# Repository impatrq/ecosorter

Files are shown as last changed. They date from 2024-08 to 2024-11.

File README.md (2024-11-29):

<div align="center">

# [Ecosorter - IMPA TRQ](https://www.instagram.com/proyecto_ecosorter24/)

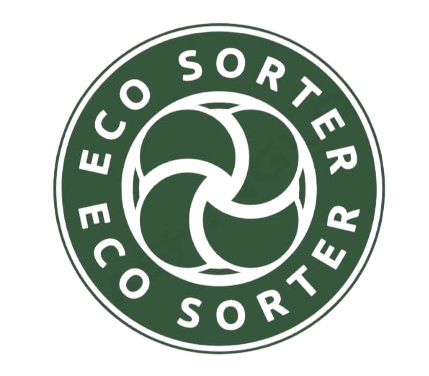
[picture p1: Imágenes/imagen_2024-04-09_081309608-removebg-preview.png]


&nbsp;

| Página web | Email | Instagram |
|---|---|---|
|[Ecosorter Web](https://eco-sorter.github.io/ecosorter/)|ecosorterimpa2024@gmail.com|[@proyecto_ecosorter24](https://www.instagram.com/proyecto_ecosorter24/)|

&nbsp;

</div>

## ¿Qué es Ecosorter?
Eco Sorter es un prototipo de un sistema de reciclaje inteligente el cual tiene como objetivo optimizar el proceso de reciclaje clasificando los residuos que se depositan en él, mediante el uso de sensores.

## ¿Cómo funciona?
El residuo depositado cae en una cesta guiada por un sistema de engranajes. Dentro de la cesta, se encuentran varios tipos de sensores que ayudan a clasificar el residuo, mientras que una cámara monitorea constantemente para determinar si es reciclable o no. Una vez identificado el tipo de residuo, el sistema de engranajes desplaza la cesta hacia la división correspondiente. La base de la cesta se abre, liberando su contenido en el recipiente adecuado. Los residuos se clasificarán en cuatro categorías.

## ¿Quiénes somos?

Somos un grupo de alumnos de E.E.S.T. N°7 "Taller Regional Quilmes" (IMPA).

### Cordoba Facundo
* 📧 facumate32@gmail.com

### Enrique Enzo
* 📧 kotamatsukami890@gmail.com

### Estevez Juan
* 📧 juanchiestevez2006@gmail.com

### Lelio Gaston
* 📧 gastonlelio05@gmail.com

### Seoane Facundo
* 📧 facuseoane40@gmail.com
  
### Spellbrinck Giuliano
* 📧 giuli8797@gmail.com

### Torrekens Lucas 
* 📧 lucas.torrekens@gmail.com
<div align="center">

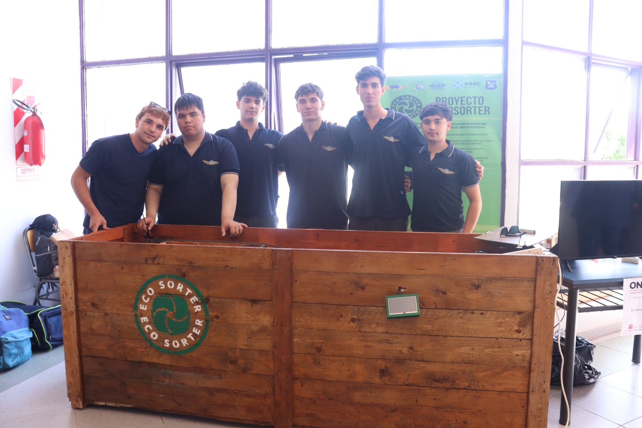
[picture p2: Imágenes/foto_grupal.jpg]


</div>

## ¿Cómo contactarnos?

* 📧 Email: ecosorterimpa2024@gmail.com

* 🌐 Página Web: https://eco-sorter.github.io/ecosorter

* 📷 Instagram: @proyecto_ecosorter24

* 🗞️ Linktr.ee: https://linktr.ee/Ecosorter

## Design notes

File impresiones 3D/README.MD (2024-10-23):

En este proyecto, se emplearon impresiones en 3D para fabricar dos piezas cilíndricas cuya función principal fue adaptar el diámetro del eje del motor al diámetro del tubo de PVC utilizado como eje de transmisión. Estas piezas resultan esenciales para garantizar un acople preciso entre ambos componentes y asegurar un funcionamiento óptimo del sistema.

Antes de imprimir las piezas finales, realizamos una prueba con una versión de menor altura y menor relleno, pero manteniendo las mismas medidas. El objetivo de esta prueba fue verificar que la pieza encajara correctamente en el tubo de PVC, ajustándose a presión. Una vez comprobado el ajuste, procedimos a imprimir las piezas definitivas.

La cantidad de adaptadores impresos en 3D necesarios depende de la cantidad de motores disponibles. En nuestro caso, contamos con dos motores, lo que nos permitió instalar una pieza adaptadora para cada uno. Este doble motor proporcionó mayor potencia al eje, optimizando el rendimiento y la capacidad de movimiento del sistema.

Es importante mencionar que, en caso de que el diámetro de la pieza impresa en 3D no encaje a presión dentro del tubo de PVC, se puede utilizar un tornillo para perforar y fijar ambas piezas de manera segura. De esta forma, se garantiza un anclaje firme, evitando movimientos indeseados o desajustes durante el funcionamiento.

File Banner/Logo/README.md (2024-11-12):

## Nuestro logo final


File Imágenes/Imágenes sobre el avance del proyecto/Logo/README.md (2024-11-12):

## Primeros logos del proyecto
#### Estas fueron algunas de las ideas que sentimos que más podían representar el proyecto.





## Logo final del proyecto
#### Hasta que dimos con los colores y el diseño correcto.


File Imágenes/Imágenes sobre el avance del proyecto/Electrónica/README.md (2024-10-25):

## Avances relacionados con la electrónica del proyecto

### Primer placa de relés que utilizamos para probar el sistema.


### Segunda placa de relés utilizada.


### Esquemático de la segunda placa de relés.


### Diseño PCB de la segunda placa de relés.


### Primer motor que intentamos adaptar, no se pudo lograr.



### Primer electroimán utilizado con la función de trabar el canasto cuando se le coloque un objeto encima, bobinado hecho a mano con pocas vueltas y no muy efectivo.


### Electroimán definitivo.


### Material ferromagnético colocado en el canasto para ser atraído por el campo del electroimán.


### Alimentación del electroimán con el Puente H L298N.


### Placa controladora de motor paso a paso TD6600, usada para mover la transmisión del canasto y la tapa elevadora del canasto.


### Esquema eléctrico de controladoras para motores NEMA 23.


### Conexiones físicas de controladoras y motores NEMA 23.


### Motores NEMA 23 acoplados al eje movilizador del canasto.


### Fuente genérica de 24V utilizada para alimentar los motores NEMA 23.


### Display LCD para representar interfaz gráfica.


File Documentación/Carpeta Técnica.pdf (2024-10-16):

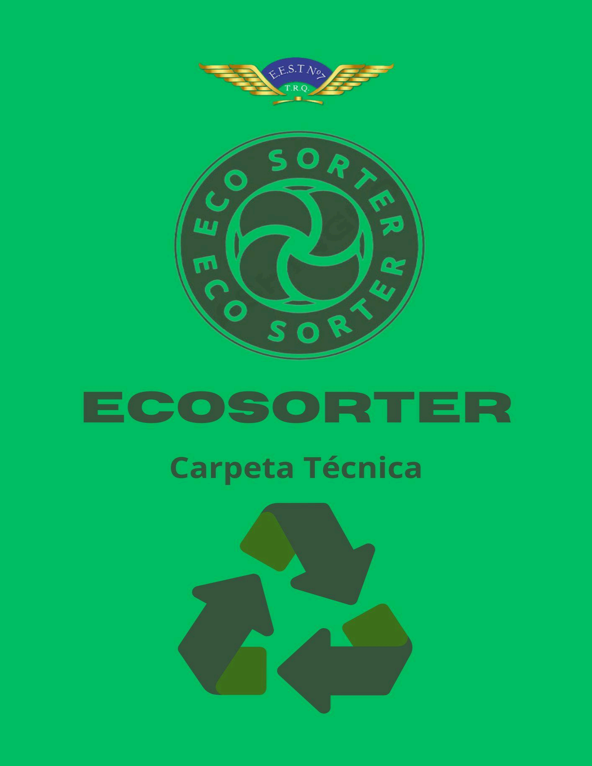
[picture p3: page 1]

# Carpeta Técnica

# Integrantes

- Facundo Cordoba Dempf
DNI: 47144440 Tel: 1122346594 Email: facundocordobadempf@impatrq.com
- Enzo Nazareno Enrique
DNI: 46702979 Tel: 1141460550 Email: enzonazarenoenrique@impatrq.com
- Juan Martin Estevez
DNI: 47144334 Tel: 1162170941 Email: juanmartinestevez@impatrq.com
- Gaston Emanuel Lelio
DNI: 46739611 Tel: 1138563418 Email: gastonemanuellelio@impatrq.com
- Facundo Seoane
DNI: 00000000 Tel: 1125137505 Email: facundoseoane@impatrq.com
- Giuliano Lorenzo Spellbrinck
DNI: 00000000 Tel: 1123670994 Email: giulianolorenzospellbrinck@impatrq.com
- Lucas Valentino Torrekens
DNI: 47119810 Tel: 1127327569 Email: lucasvalentinotorrekens@impatrq.com

# Docentes a tutores

- Sergio Medina
- Fabricio Carlassara
- Carlos Bianco
- Julian Scicolone

# Fecha deinicio

- 1 de Abril de 2024

# Fecha deentrega

- 09 de octubre de 2024

# Duración

- 27 semanas

# Trabajo semanal

- 8 horas semanales

# RedesSociales

- Instagram: https://www.instagram.com/proyecto_ecosorter24
- LinkTree: https://linktr.ee/Ecosorter
- Página Web: https://eco-sorter.github.io/ecosorter/
- Email: ecosorterimpa2024@gmail.com

# ¿QuéesEcosorter?

Ecosorter es un proyecto desarrollado en la Escuela de Educación Secundaria Técnica Nº7, cuyo principal objetivo es optimizar el proceso de reciclaje y fomentar la conciencia sobre la importancia de reciclar en la vida cotidiana. A través de soluciones innovadoras y prácticas, este proyecto busca mejorar la eficiencia en la clasificación de residuos, promoviendo hábitos sustentables y contribuyendo al cuidado del medio ambiente.

# Objetivo

El objetivo principal de Ecosorter es optimizar el proceso de reciclaje mediante un sistema automatizado y eficiente, que no solo facilita la clasificación de residuos, sino que también fomenta la conciencia ambiental en la vida cotidiana de las personas. Al integrar tecnología avanzada como la inteligencia artificial y sensores inteligentes, el proyecto busca mejorar la precisión con la que se separan los distintos tipos de materiales reciclables, como plásticos, cartones, vidrios y metales. Esto contribuye directamente a reducir la cantidad de residuos que terminan en vertederos, apoyando así un enfoque más sustentable en la gestión de residuos.

Además de la eficiencia técnica, Ecosorter tiene como meta generar un impacto social al promover hábitos de reciclaje y prácticas responsables entre los usuarios. El sistema de incentivos por puntos, que premia a las personas por su participación activa en el reciclaje, refuerza este objetivo al convertir el reciclaje en una tarea recompensada y valorada. De esta forma, Ecosorter no solo optimiza el proceso, sino que también se convierte en una herramienta educativa, fomentando un cambio de comportamiento en la comunidad que puede tener un impacto positivo a largo plazo en la sostenibilidad.

# Funcionamiento

El Ecosorter funciona mediante un sistema que clasifica y deposita los distintos tipos de residuos en cestos separados: plásticos y cartones, vidrios, residuos y metales. La clasificación se realiza utilizando una cámara configurada con inteligencia artificial entrenada por el equipo y un sensor capacitivo que detecta la llegada de un objeto. El sistema está instalado en un canasto miniatura, conectado a dos ejes mediante cadenas de bicicleta, accionado por un motor paso a paso.

Cuando el canasto llega al cesto correspondiente, otro motor paso a paso abre una compuerta para depositar el objeto. Como los motores paso a paso no son capaces de mantener una posición, como si lo hacen los servos, elaboramos un electroimán capaz de mantener la compuerta cerrada. Después de depositar el objeto, el canasto regresa a su posición inicial. Cada cesto tiene un sensor de ultrasonido que mide la capacidad ocupada, y esta información se muestra en un display frontal. Todo el sistema es controlado por una Raspberry Pi 4, que coordina las señales de los sensores y ejecuta las acciones correspondientes.

# Aplicación a la vida cotidiana

De acuerdo con estudios realizados por la Agencia de Protección Ambiental (EPA), aproximadamente un 60% del material reciclable se desperdicia debido a la falta de separación adecuada, lo que contribuye a la contaminación y aumenta los costos de producción de nuevos elementos. Con nuestro proyecto, Ecosorter, buscamos reducir significativamente ese porcentaje, facilitando el proceso de reciclaje y promoviendo una mayor eficiencia en la gestión de residuos.

La visión es que Ecosorter pueda integrarse en la vida cotidiana, ubicándose en espacios públicos como aeropuertos, plazas, fábricas, escuelas, entre otros, para hacer el reciclaje más accesible y automático, generando así un impacto positivo en el medio ambiente y la sociedad.

# Sistema depuntos

Como parte del incentivo para fomentar el reciclaje, se ha implementado un sistema de puntos en el que cada usuario acumula puntos por depositar correctamente los residuos. Los materiales reciclables tienen distintos valores:
- plástico o cartón 5 puntos
- vidrio 10 puntos
- metal 10 puntos
- residuos 10 puntos
Estos puntos acumulados pueden ser canjeados por diversas recompensas disponibles en la sección de catálogos.

# Hardware

## Alimentación

La alimentación del sistema se lleva a cabo por los siguientes componentes:

### Fuente alimentación 12v 40A

La fuente de alimentación de 12v 40A alimenta al electroimán y al driver Tb6600 para que pueda amplificar la señal recibida por la raspberry pi 4.

### Transformador 5v 3A

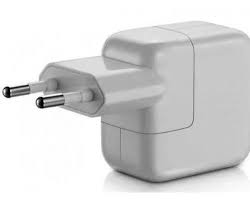
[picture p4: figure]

Utiliza un transformador de 5V 3A, comúnmente empleado como cargador de celular, para alimentar la Raspberry Pi 4, asegurando un suministro estable de energía para manejar los motores, sensores y el procesamiento de imágenes. Adicionalmente, se utiliza otro transformador dedicado para alimentar la pantalla LCD de 5 pulgadas, lo que permite evitar sobrecargas y garantizar el correcto funcionamiento de todos los componentes del sistema.

## Clasificación

La clasificación de objetos de Ecosorter se lleva a cabo gracias a los siguientes componentes:

### Sensor capacitivo

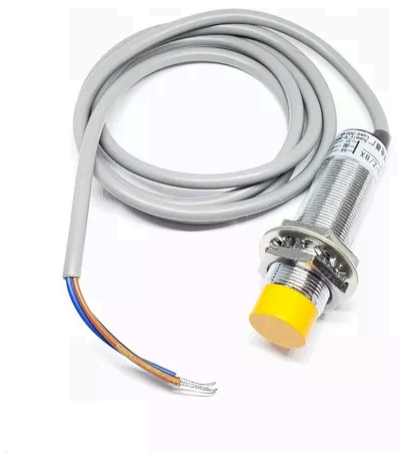
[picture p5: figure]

El sensor capacitivo es el encargado de indicar a la raspberry pi 4 cuando un objeto ha llegado al canasto de clasificación. Su funcionamiento se basa en la medición de los cambios en la capacitancia de un campo eléctrico que genera. Cuando un objeto entra en el área de detección, altera la capacitancia, lo que permite al sensor identificar su presencia.

Una vez que el objeto es depositado en su respectivo cesto, el sensor deja de detectar cambios en la capacitancia, lo que indica que no hay más objetos en el canasto de clasificación. En ese momento, el sistema instruye al canasto para que regrese a su posición inicial, quedando listo para recibir el siguiente objeto a clasificar.

### Cámara Web

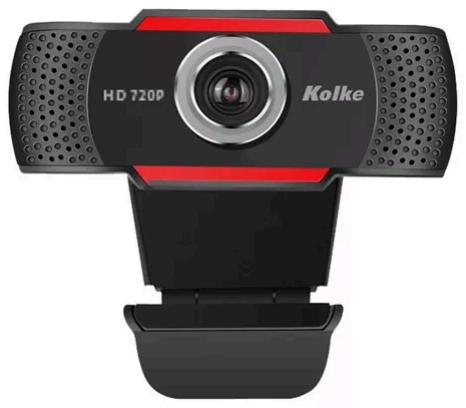
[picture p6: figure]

La cámara, equipada con inteligencia artificial, es la encargada de clasificar los distintos objetos que se ingresan al sistema. Su función es identificar el tipo de material del objeto y, una vez que el sensor capacitivo ha detectado la presencia de un objeto, la cámara se activa para realizar el análisis. Solo después de que el sensor capacitivo esté activado, la cámara envía la señal con la clasificación del objeto, permitiendo que el sistema proceda a depositarlo en el cesto correspondiente.

## Depositado

El depositado de objetos se lleva a cabo por los siguientes componentes:

### Motor paso a paso (movimiento delosejes)

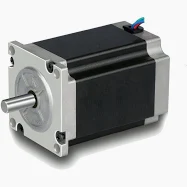
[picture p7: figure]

El motor utilizado es un NEMA 23, encargado de accionar los ejes móviles del Ecosorter. Al ser un motor paso a paso, su principal característica es la precisión en el control del movimiento, lo que permite indicar exactamente cuánto y en qué dirección debe moverse. La Raspberry Pi 4 es la encargada de enviar las señales necesarias al motor, especificando tanto la dirección como la cantidad de pasos que debe ejecutar para posicionar el canasto en el cesto correspondiente.

### Motor paso a paso (Apertura compuerta delcanasto)

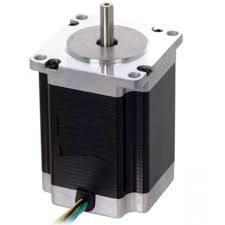
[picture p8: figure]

Al igual que el motor que mueve los ejes, se utiliza un motor paso a paso NEMA 23 para abrir y cerrar la compuerta del canasto de clasificación. La Raspberry Pi 4 es responsable de enviar las señales necesarias para controlar el motor, indicando cuándo debe abrirse o cerrarse la compuerta.

### Driver tb6600

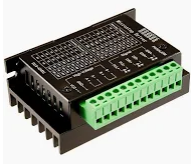
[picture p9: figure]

El TB6600 es un controlador de motor paso a paso de alto rendimiento, utilizado para manejar motores como el NEMA 23. Permite un control preciso del motor, soportando diferentes niveles de corriente y micro-pasos, lo que garantiza un funcionamiento suave y eficiente. Es ideal para aplicaciones que requieren movimientos exactos y repetitivos, como el accionamiento de los ejes en el proyecto o la apertura de la compuerta del canasto de clasificación.

### Electroimán

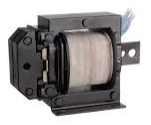
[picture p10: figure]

El electroimán fue fabricado por nosotros, enrollando alambre de cobre esmaltado alrededor de un metal ferroso. Este está conectado en paralelo con un diodo Zener, para manejar los picos de corriente, y en serie con resistencias de potencia, que disipan la energía generada. Su función es mantener la compuerta del canasto de clasificación cerrada, ya que el motor paso a paso no tiene la capacidad de mantener una posición fija.

L298n

El L298N permite controlar este flujo de corriente desde una Raspberry Pi 4, activando o desactivando el electroimán según sea necesario. Cuando el microcontrolador envía señales a los pines de entrada del L298N, este permite que la corriente circule, activando el electroimán para mantener la compuerta cerrada. Además, el L298N proporciona protección contra picos de corriente generados al apagar el electroimán, asegurando un control estable y seguro del sistema.

## Porcentaje decarga

Para poder conocer el porcentaje de carga de los cestos se utilizan los siguientes componentes:

### Sensores de ultrasonido

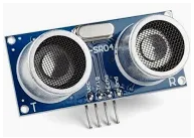
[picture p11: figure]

Se utilizan cuatro sensores ultrasónicos HC-SR04, correspondientes a la misma cantidad de cestos de residuos. Cada sensor mide distancias mediante ultrasonidos, emitiendo una señal que rebota en un objeto y regresa al sensor. La distancia se calcula midiendo el tiempo que tarda la señal en ir y volver. El rango de detección de estos sensores es de 2 cm a 400 cm, con una precisión de ±3 mm. Su función principal es monitorear la capacidad de los cestos de residuos, y las señales censadas son enviadas a la Raspberry Pi 4 para su procesamiento y análisis.

### Pantalla LCD

El sistema cuenta con una pantalla LCD de 5 pulgadas que muestra el nivel de llenado de los cestos. Cuando un cesto llega al 100%, notifica al usuario que debe cambiar la bolsa correspondiente. Además, tras almacenar el objeto, se genera un código QR para que el usuario canjee los puntos obtenidos según el tipo de residuo clasificado.

## Microcontrolador

El microcontrolador encargado de generar todas las órdenes y procesar todas las señales de los sensores es:

### Raspberrypi 4

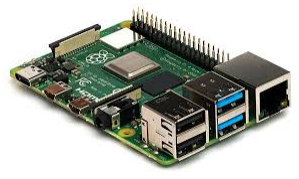
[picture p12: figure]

La Raspberry Pi 4, como se mencionó anteriormente, es la responsable de generar todas las órdenes y procesar las señales recibidas de los sensores, garantizando que el funcionamiento del Ecosorter sea óptimo y efectivo.

# Software

## Python

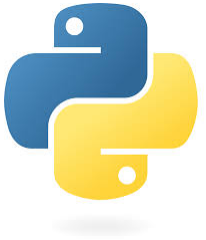
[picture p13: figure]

Python es el lenguaje principal que se utilizó para controlar las operaciones del sistema, desde el manejo de sensores hasta el control de motores y la gestión de la cámara de inteligencia artificial. Su flexibilidad y disponibilidad de bibliotecas hacen de Python una excelente opción para este tipo de proyectos.

## OpenCV

Utilizado para procesar las imágenes capturadas por la cámara, OpenCV se encargó de ejecutar la clasificación de objetos mediante algoritmos de visión por computadora, detectando de manera precisa los materiales depositados en el canasto.

## YOLOv8

YOLOv8 es un modelo de inteligencia artificial optimizado para la detección rápida

de objetos. Fue entrenado para clasificar los residuos en distintas categorías, permitiendo que el sistema identifique rápidamente el tipo de material (plásticos, cartones, vidrios, metales, residuos).

## HTML,Flask,CSS,yJavaScript

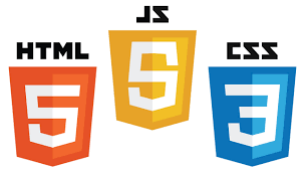
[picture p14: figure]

Estas tecnologías se emplearon para desarrollar la interfaz gráfica que muestra la capacidad de los cestos de residuos en tiempo real. A través de HTML se estructura la visualización, CSS asegura un diseño atractivo y claro, mientras que JavaScript permite la interactividad. Flask gestiona la conexión entre la interfaz y los datos generados por los sensores de ultrasonido, además de generar un código QR que permite a los usuarios canjear puntos acumulados.

## PHPySQL

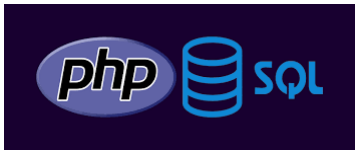
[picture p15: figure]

El sistema de puntos fue diseñado utilizando PHP para gestionar el backend y SQL para almacenar los datos de usuarios, puntos y recompensas. Esta información es gestionada en un servidor alojado en Infinite Free, donde los usuarios pueden acceder para verificar y canjear sus puntos luego de reciclar un objeto, escaneando el QR mostrado en la interfaz.

## Raspbian OS

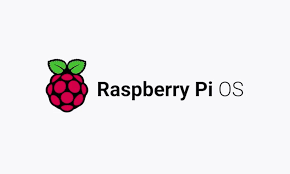
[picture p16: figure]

La Raspberry Pi 4 corre bajo Raspbian OS, un sistema operativo basado en Linux. Este OS maneja las funciones de hardware y software del dispositivo, permitiendo que todos los componentes trabajen juntos eficientemente.

## GPIOZero y RPi.GPIO

GPIOZero y RPi.GPIO son bibliotecas de Python que permiten interactuar con los pines GPIO de la Raspberry Pi. Estos se utilizaron para controlar los distintos componentes de hardware, como los motores y sensores, garantizando la correcta ejecución de las tareas.

# PCBs Utilizados

## PCB Raspberrypi 4

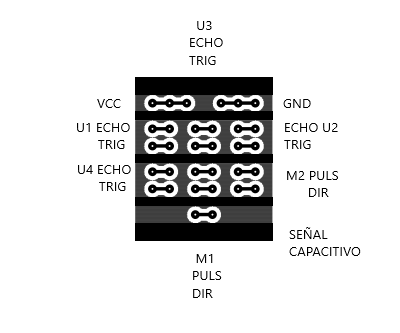
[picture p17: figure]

## PCB ultrasonidos

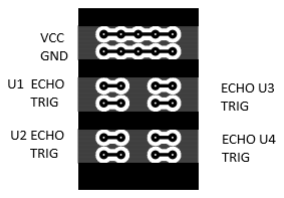
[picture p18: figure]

## PCB Canasto

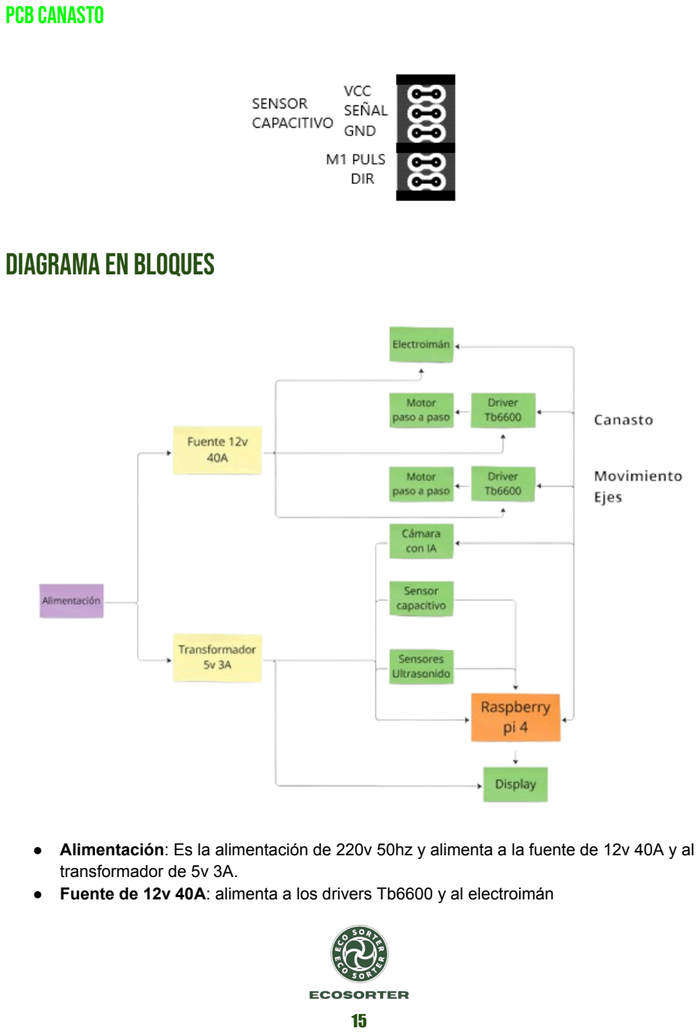
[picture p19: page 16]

# Diagrama en bloques

- Alimentación: Es la alimentación de 220v 50hz y alimenta a la fuente de 12v 40A y al transformador de 5v 3A.
- Fuente de 12v 40A: alimenta a los drivers Tb6600 y al electroimán

- Transformador 5v 3A: alimenta a la Raspberry pi 4 y al display.
- Raspberry pi 4: Alimenta al sensor capacitivo, a los sensores de ultrasonido, a la cámara y al servomotor. Recibe las señales de los sensores, de la cámara y de la posición del servomotor y en base a esto ordena las respectivas tareas a la cámara, al driver Tb6600, al display y al servomotor.
- Sensor capacitivo: detecta si llego un objeto al canasto de clasificación y le envía la señal a la Raspberry pi 4.
- Sensores de ultrasonido: miden la capacidad de los cestos y le envían la información a la Raspberry pi 4.
- Display: Enseña la capacidad de los cestos y el qr con los puntos a canjear. Información enviada por la Raspberry pi 4.
- Cámara con IA: configurada con inteligencia artificial, si detecta un objeto envía la información a la Raspberry pi 4.
- Servomotor: recibe la señal sobre que posición debe estar proveniente de la Raspberry pi 4 y le envía esta misma información al microcontrolador también.
- Driver Tb6600: Recibe la información sobre cuántos pasos debe hacer el motor recibida desde la Raspberry pi 4. Luego envía la señal amplificada al motor.
- Motor paso a paso Nema 23: Recibe la señal amplificada proveniente del driver Tb6600 y acciona en base a esa información.
- Electroimán: Recibe la señal de la Raspberry pi 4 y si es activado genera campo electromagnético.

# Diagrama deflujo

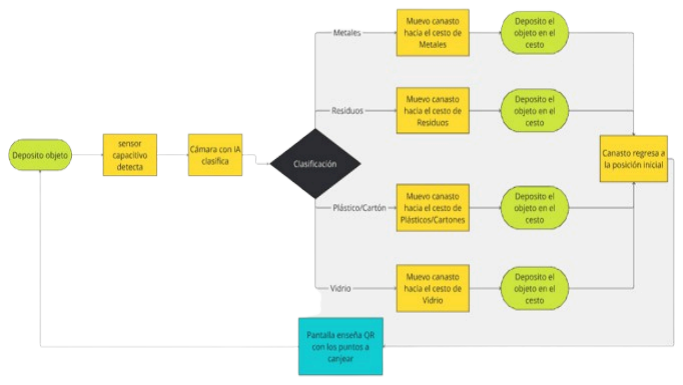
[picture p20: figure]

- Paso 1: Deposito el objeto en el canasto clasificador.
- Paso 2: Sensor capacitivo detecta que llegó un objeto.
- Paso 3: La cámara configurada con IA clasifica el objeto.
- Paso 4 (Metal): Se moviliza el canasto de clasificación hacia el cesto de metales.
- Paso 4 (Residuo): Se moviliza el canasto de clasificación hacia el cesto de residuos
- Paso 4 (Plástico/Cartón): Se moviliza el canasto de clasificación hacia el cesto de plásticos/cartones.
- Paso 4 (Vidrio): se moviliza el canasto de clasificación hacia el cesto de vidrios.
- Paso 5: Se deposita el objeto en el canasto abriendo y cerrando la compuerta con el servo y encendiendo el electroimán para sostener.
- Paso 6: El canasto de clasificación regresa a la posición inicial.
- Paso 7: El QR con los puntos a canjear estará en la pantalla listo para escanear.

Se repite el ciclo.

# Interfazgráfica

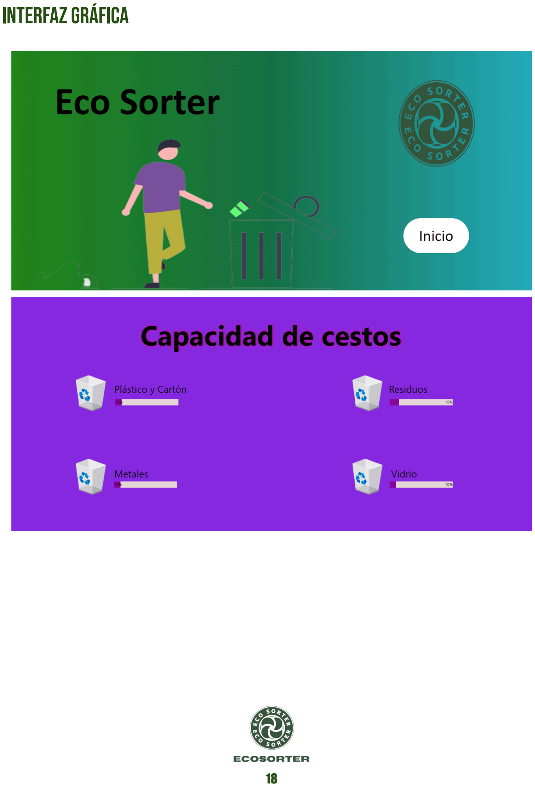
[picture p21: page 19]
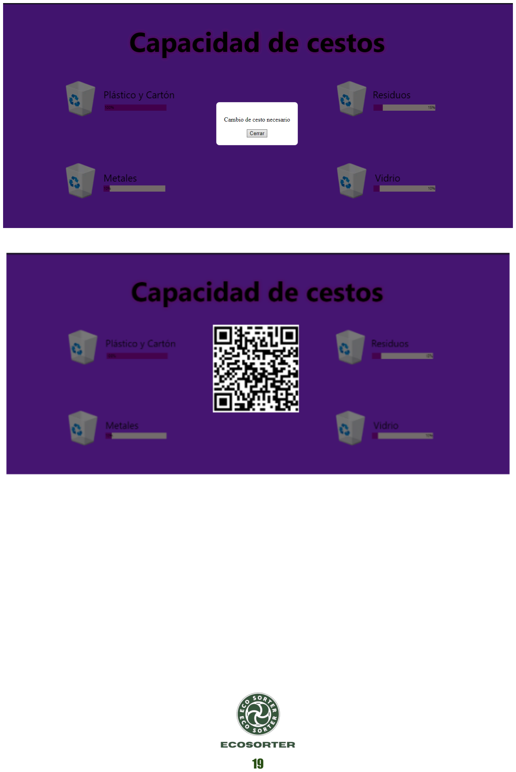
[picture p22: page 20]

# Página desistema depuntos

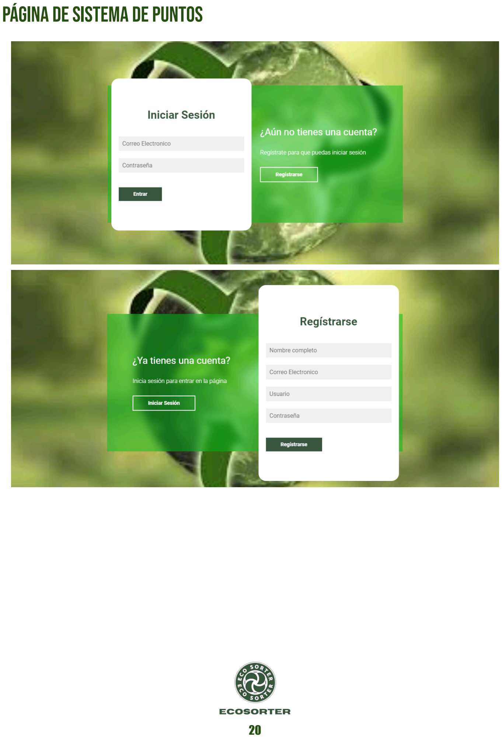
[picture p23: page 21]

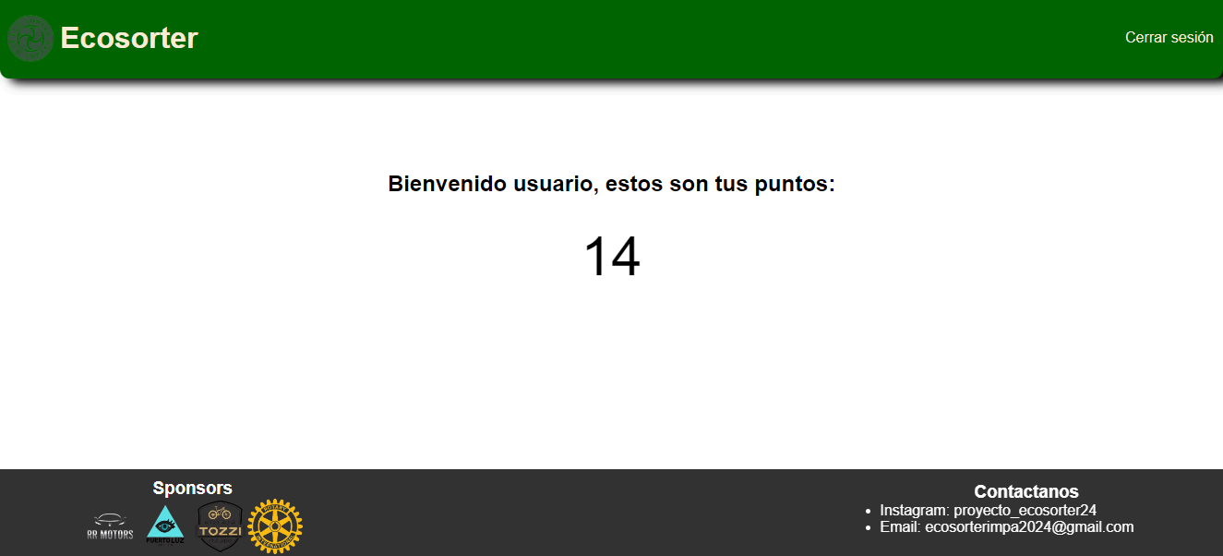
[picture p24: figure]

# Fotos delEcosorter

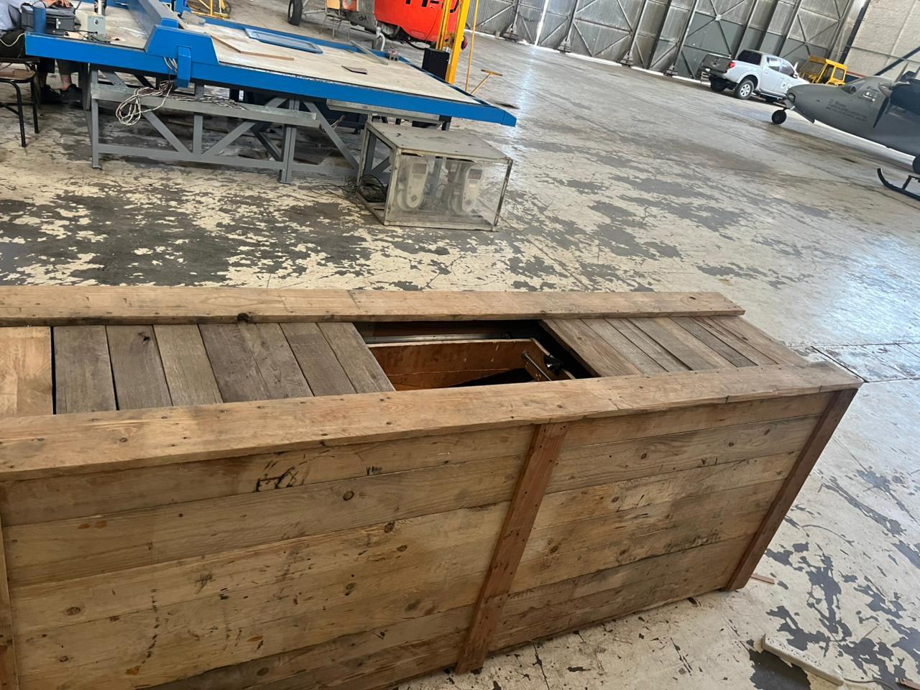
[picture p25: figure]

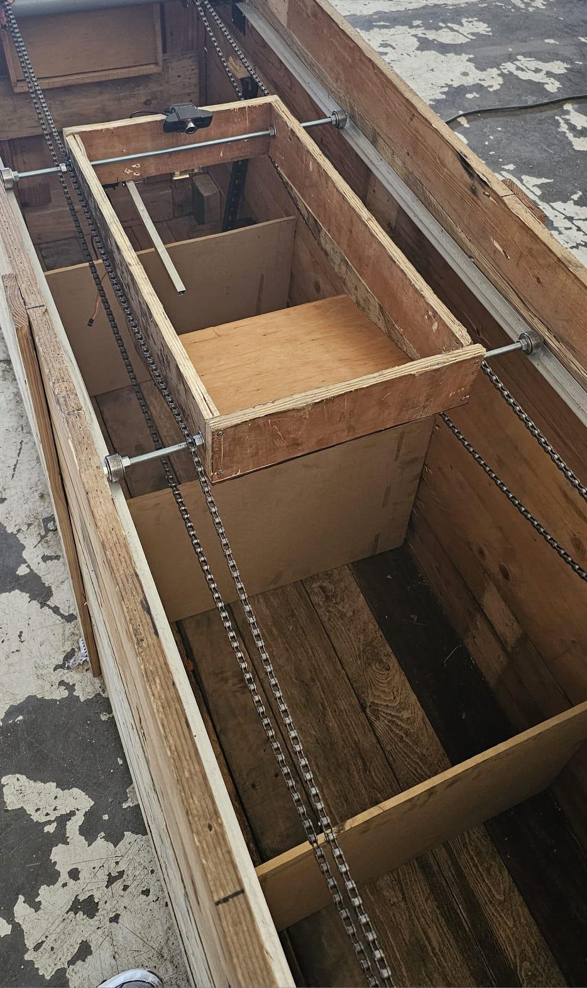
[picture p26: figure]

## Ecosorter representa un avancesignificativo en la gestión de

## residuos, brindando una solución práctica yeducativa para

## mejorar el reciclajeen la vida cotidiana, altiempo que

## incentiva la participación activa dela comunidad a través de

un sistema de recompensas.

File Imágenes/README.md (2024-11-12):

## En esta carpeta dejamos algunas imágenes sobre el avance en general del proyecto.

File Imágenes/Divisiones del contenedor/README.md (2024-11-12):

## Imágenes de las divisiones de los cestos

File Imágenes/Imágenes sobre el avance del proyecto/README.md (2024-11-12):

## A continuación dejaremos más imágenes sobre el avance del proyecto

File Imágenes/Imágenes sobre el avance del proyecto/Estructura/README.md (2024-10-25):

## Carpeta donde se verán los diseños y avance de la estructura

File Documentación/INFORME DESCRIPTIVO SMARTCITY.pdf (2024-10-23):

## Integrantes:

DNI: 46876534
Correo: facundoseoane@impatrq.com

DNI: 47144334
Correo: juanmartinestevez@impatrq.com

DNI: 46739611
Correo: gastonemanuellelio@impatrq com

DNI: 47144337
Correo: giulianolorenzospellbrinck@impatrq.com

DNI: 47119810
Correo: lucasvalentinotorrekens@impatrq.com

DNI: 46702979


# ECO SORTER SMARTCITY PROYECT

# E.E.S.T. N7

Seoane Facundo

Estevez Juan Martín

Lelio Gaston Emanuel

Spellbrinck Giuliano Lorenzo:

Torrekens Lucas Valentino

Enrique Enzo Nazareno

Correo: enzonazarenoenrique@impatrq.com

DNI: 47144440
Correo: facundocordobadempf@impatrq.com

En el marco del concurso "Propuestas Ambientales de Futuro Sostenible", presentamos Ecosorter, un sistema automatizado de reciclaje que optimiza la gestión de residuos de manera sostenible. Este proyecto se alinea con los Objetivos de Desarrollo Sostenible (ODS), promoviendo la reducción de desechos y fomentando una cultura de reciclaje responsable, con el objetivo de contribuir a un futuro más sostenible tanto a nivel local como nacional.

Ecosorter es un sistema automatizado cuya función es optimizar el proceso de reciclaje mediante la clasificación de residuos de forma inteligente. Funciona de manera autónoma, detectando y clasificando los objetos a través de sensores y una cámara con inteligencia artificial. Los residuos se clasifican en categorías como plásticos, cartones, vidrios, metales o residuos orgánicos.
Luego, un motor paso a paso acciona un canasto que transporta el residuo hacia el cesto adecuado, y un servomotor abre el piso del canasto dejando caer el objeto en el cesto correspondiente .
Los cestos tienen sensores de ultrasonido que miden su capacidad y envían los datos a una Raspberry Pi 4, la cual gestiona el sistema.
Además, Ecosorter incluye un sistema de incentivos donde los usuarios ganan puntos al reciclar, que pueden canjear por recompensas a través de

Córdoba Dempf Facundo

# INTRODUCCION

# RESUMEN DEL PROYECTO

una plataforma gestionada con PHP y SQL.

Comenzamos el desarrollo del proyecto reacondicionando dos cajones de madera que se encontraban en la escuela los cuales albergaban motores , transformadolos en la estructura principal del proyecto con una altura de 88cm , un ancho de 240cm y una longitud de 66cm.


Una vez terminado el contenedor principal comenzamos a desarrollar las guías por las que se desplazaria el canasto utilizando dos "T" de aluminio qué recorren todo el largo de la estructura. Reciclando tubos pvc realizamos los ejes sobre los que se desplazaran las cadenas qué mueven al canasto , en cada eje colocamos dos piñones para poder colocar las cadenas .
Una vez terminado todo el sistema sobre el que se movería el canasto , se comenzó con el prototipo del canasto el cual fue hecho sobre madera , instalandole un sistema que consta de 4 varillas roscadas con rulemanes en sus extremos los cuales permiten el movimiento del canasto. Posteriormente se le añadieron a su estructura la cámara y el sensor capactivo para la detección del tipo de residuo . En la parte inferior del contenedor se encuentran las divisiones según el tipo de residuo también hechas en madera

# DESARROLLO DEL PROYECTO


Una vez terminada la estructura la misma fue lijada y posteriormente pintada de verde
En tanto a electronica y programación comenzamos programando la interfaz gráfica que muestra la capacidad de cada cesto en el display q se encuentra en el exterior del contenedor y configurando los sensores ultrasonido ubicados en cada cubículo.


Terminado el programa de la interfaz gráfica, continuamos con la programación y el entrenamiento de la inteligencia artificial Yolov8 para que sea capaz de reconocer los distintos tipos de residuos mediante la utilización de la cámara situada en el canasto.


Una vez realizados estos dos programas continuamos con la configuración del servomotor y del sensor capacitivo para que puedan detectar la presencia de un objeto en el canasto , y que una vez reconocido el objeto ,el piso del canasto se abra dejandolo caer en el cubículo correspondiente.


Continuamos configurando el driver tb6600 para poder controlar el motor paso a paso indicándole cuantos pasos tiene q dar y a que velocidad para mover el canasto a cada cubículo


Por último se programo y realizo un sistema de puntos con los lenguajes PHP y MySQL a modo de incentivo el cual funciona asignando un cierto puntaje cada vez que reciclemos correctamente un residuo utilizando Ecosorter .


Luego continuamos con el desarrollo de 4 placas en PCB cuyas funcionalidades son :
Alimentar y recibir la señal de los sensores ultrasonido
Para que el driver pueda instruir al motor
Para la comunicación de la RaspBerry Pi4 con todo el sistema Para alimentar y recibir la señal del sensor capacitivo

Una vez terminados estos procesos desarrollamos los manuales y la página Web del proyecto .

La temática principal de Ecosorter se centra en la sostenibilidad y la gestión eficiente de residuos a través del reciclaje. En la actualidad, el mundo enfrenta una crisis ambiental derivada de la mala gestión de los residuos y el exceso de desechos no reciclados, que afectan no solo a los ecosistemas, sino también a la salud pública y a la calidad de vida en las ciudades. Uno de los principales desafíos es la incorrecta separación de los residuos en los hogares, escuelas y espacios públicos, lo que provoca que materiales reciclables como plásticos, metales, vidrios y cartones terminen en vertederos, perdiendo su potencial de reutilización.
El mal manejo de residuos también contribuye a la contaminación de suelos y cuerpos de agua, a la generación de gases de efecto invernadero, y al uso excesivo de recursos naturales para producir nuevos materiales, en lugar de reutilizar los ya existentes. En este contexto, Ecosorter se presenta como una solución práctica y tecnológica que busca mejorar la eficiencia del reciclaje al facilitar la correcta clasificación de los residuos en el momento en que son depositados, automatizando un proceso que muchas veces es ignorado o mal ejecutado por los usuarios.
Ecosorter además se alinea con las metas globales de desarrollo sostenible, en particular con los Objetivos de Desarrollo Sostenible (ODS) de la ONU, como el ODS 12 (Producción y Consumo Responsables) y el ODS 13 (Acción por el Clima). El proyecto no solo es una solución local para la gestión de residuos, sino que también puede ser parte de un esfuerzo global por reducir el impacto ambiental y promover una economía circular, donde los materiales son reutilizados en lugar de desechados.

# IMPACTO AMBIENTAL

# BENEFICIOS SOCIALES

Ecosorter no solo facilita el proceso de reciclaje, sino que también desempeña un papel crucial en la educación ambiental, fomentando la importancia del reciclaje desde una edad temprana. El proyecto puede integrarse en programas educativos en escuelas y campañas de sensibilización comunitarias, ayudando a los jóvenes y adultos a desarrollar hábitos responsables en la gestión de residuos. A través de incentivos como el sistema de puntos, se motiva a la población a reciclar, creando un compromiso social activo. Además, la visibilidad pública de dispositivos como Ecosorter en espacios comunitarios puede generar conversaciones y conciencia en torno a la reducción de la huella de carbono y el consumo responsable.
El proyecto Ecosorter es altamente adaptable y tiene el potencial de ser implementado en múltiples ubicaciones geográficas. Se puede instalar en una variedad de entornos urbanos y rurales, optimizando la gestión de residuos en aeropuertos, plazas, fábricas, centros comerciales, escuelas y oficinas públicas. Gracias a su diseño compacto y su tecnología escalable, Ecosorter puede adaptarse tanto a áreas con alta densidad de población como a comunidades más pequeñas, contribuyendo a la reducción de residuos en cualquier lugar. Además, la integración de tecnologías de detección y monitoreo remotos permite gestionar los puntos de reciclaje en tiempo real, lo que es ideal para ciudades inteligentes y municipios que buscan mejorar sus políticas de reciclaje.

Ecosorter se vincula estrechamente con los Objetivos de Desarrollo Sostenible (ODS) de la ONU, particularmente con los ODS 12, 13 y 15, de la siguiente manera:

- Gestión sostenible y uso eficiente de los recursos naturales: Ecosorter optimiza el proceso de reciclaje, garantizando una mejor gestión de los

# ECO SORTER YLOS ODS

ODS 12: Garantizar modalidades de consumo y producción sostenibles residuos. Al clasificar los materiales reciclables de forma automatizada, promueve la reutilización y el reciclaje de recursos, reduciendo la dependencia de la extracción de materias primas.

- Reducción de desechos mediante reciclado y reutilización: El sistema se enfoca en reducir considerablemente la generación de desechos. Al clasificar de manera eficiente los residuos, facilita la reintroducción de materiales reciclables en la cadena de producción, promoviendo un ciclo de vida sostenible de los productos.
- Fomento de conductas personales para reducir el impacto climático: Ecosorter incluye un sistema de incentivos donde los usuarios ganan puntos al reciclar. Esto alienta a las personas a reciclar más y a ser conscientes de su impacto en el medio ambiente, contribuyendo a una cultura de consumo responsable.
- Promoción de acciones industriales para reducir la contaminación: Ecosorter facilita la separación y el reciclaje, permitiendo a las industrias reutilizar materiales reciclados en lugar de depender de nuevos recursos. Esto reduce tanto la energía necesaria para producir nuevos materiales como la cantidad de desechos que terminan en vertederos, ayudando a disminuir las emisiones de gases de efecto invernadero.
- Protección y rehabilitación de los suelos y ecosistemas: Al reducir la cantidad de desechos mal gestionados que pueden acabar contaminando el suelo y los cuerpos de agua, Ecosorter contribuye indirectamente a la

ODS 13: Adoptar medidas urgentes para combatir el cambio climático y sus efectos

ODS 15: Proteger los ecosistemas terrestres y luchar contra la desertificación protección de los ecosistemas. Además, al promover el reciclaje, reduce la presión sobre la extracción de recursos naturales, ayudando a la conservación de bosques y tierras degradadas.

En resumen, Ecosorter apoya el uso eficiente de recursos, fomenta comportamientos responsables hacia el reciclaje y ayuda a mitigar los impactos del cambio climático, contribuyendo a la sostenibilidad de los ecosistemas.

-Importancia de Ecosorter a nivel nacional y provincial (Argentina y Buenos Aires)

# IMPORTANCIA DEECO SORTER

A nivel nacional, Ecosorter puede tener un impacto significativo en la mejora de la gestión de residuos sólidos urbanos en Argentina, un país que enfrenta serios desafíos en cuanto al tratamiento adecuado de sus residuos. Según datos recientes, más del 40% de los residuos en Argentina terminan en vertederos sin tratamiento adecuado. Ecosorter puede contribuir a la reducción de este porcentaje al facilitar el reciclaje automatizado y eficiente, promoviendo una economía circular que reutilice materiales en lugar de desecharlos. Su implementación a nivel nacional podría ayudar a reducir la presión sobre los vertederos, mejorar la calidad del aire y del agua, y disminuir las emisiones de gases de efecto invernadero. Además, el sistema de incentivos motivaría a los ciudadanos a adoptar hábitos de reciclaje más sostenibles, creando un impacto cultural positivo en la conciencia ambiental de la población.

En la provincia de Buenos Aires, donde reside más de un tercio de la población argentina, Ecosorter podría jugar un papel clave en la mejora de la gestión de residuos en áreas urbanas densamente pobladas como el conurbano bonaerense, donde la disposición de residuos es un problema crítico. Municipios de la provincia podrían integrar Ecosorter en sus políticas de recolección de residuos, optimizando los recursos

Ecosorter es un sistema altamente adaptable, capaz de ser implementado en diversas escalas y contextos geográficos. Su diseño modular permite que sea utilizado tanto en entornos urbanos como rurales, optimizando la gestión de residuos en espacios de alta densidad como aeropuertos, centros comerciales, plazas, escuelas y fábricas, así como en comunidades más pequeñas.

Gracias a la flexibilidad de su estructura, que fue creada a partir del reacondicionamiento de materiales reciclados, Ecosorter puede ser ajustado en tamaño y configuración para satisfacer las necesidades específicas de cada ubicación. Además, el uso de tecnología como la Raspberry Pi 4 y los sensores ultrasonido facilita su escalabilidad a nivel de hardware, permitiendo la expansión del sistema a nuevas áreas sin necesidad de modificar su núcleo tecnológico. Esto lo convierte en una solución accesible y personalizable para diversas comunidades que busquen mejorar su gestión de residuos

Ecosorter está perfectamente alineado con la visión de las ciudades inteligentes (Smart Cities), dado su enfoque en la automatización y el uso eficiente de datos. La capacidad del sistema de enviar información en tiempo real sobre la capacidad de los cestos, a través de sensores de ultrasonido conectados a la Raspberry Pi 4, permite que los gestores de residuos tomen municipales y reduciendo los costos asociados al transporte y tratamiento de desechos. Además, al ser adaptable a diversas escalas, Ecosorter podría implementarse en municipios de menor tamaño, contribuyendo al desarrollo sostenible en áreas rurales. Este proyecto podría ser una herramienta clave para que Buenos Aires avance en la consecución de los Objetivos de Desarrollo Sostenible (ODS), en particular los relacionados con la producción y el consumo responsable y la acción climática.

# ESCALABILIDAD

# INTEGRACION CON CIUDADES INTELIGENTES

decisiones informadas para optimizar las rutas de recolección y evitar desbordamientos.

Además, la plataforma basada en PHP y SQL para el sistema de incentivos puede ser integrada en aplicaciones móviles de gestión municipal, brindando a los ciudadanos una interfaz sencilla para monitorizar sus puntos de reciclaje y contribuir al esfuerzo comunitario. Este tipo de integración con plataformas digitales ayuda a mejorar la eficiencia en el manejo de recursos y refuerza el concepto de ciudad sostenible y tecnológicamente avanzada

### 1. Incentivar el reciclaje con recompensas: Implementar un sistema de

puntos a través de Ecosorter, donde los usuarios ganen beneficios por cada material correctamente reciclado, que podrán canjear por productos o servicios locales, fomentando hábitos sostenibles en la comunidad.

### 2. Talleres de educación ambiental: Organizar talleres en escuelas, centros

comunitarios y vecinales para enseñar sobre la correcta separación de residuos y la importancia del reciclaje, integrando Ecosorter como una herramienta pedagógica.

### 3. Puntos de reciclaje en espacios públicos: Instalar estaciones de Ecosorter

en plazas, parques y centros comerciales, facilitando a los ciudadanos el acceso a un sistema de reciclaje eficiente y automatizado en sus entornos cotidianos.

### 4. Programas de recolección eficiente: Coordinar con los municipios para

integrar Ecosorter en las rutas de recolección de residuos, optimizando los recursos y reduciendo los costos de transporte y tratamiento de desechos mediante la clasificación previa de los materiales reciclables.

# PROPUESTAS PARA LA COMUNIDAD

### 5. Campañas de concientización digital: Lanzar campañas en redes sociales y

plataformas locales para informar a los ciudadanos sobre los beneficios del reciclaje y el uso de Ecosorter, promoviendo una mayor participación comunitaria en la protección del medio ambiente.

Aquí están algunos sitios de los que obtuvimos información para desarrollar este documento

También realizamos nuestra propia encuesta para saber el nivel de conocimiento sobre reciclaje en nuestra Escuela

# REFERENCIAS BIBLIOGRAFICAS

https://www.unep.org/
https://greenandnatural.org/https://www.deloitte.com/

https://docs.google.com/forms/d/e/1FAIpQLSfTPexUbuM_qgpQLXOYWAzEf3eX7pFoXo1kzsclfJsYe2bXbA/viewform

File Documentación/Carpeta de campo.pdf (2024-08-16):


# Carpeta decampo

# Integrantes:

- Facundo Cordoba Dempf
DNI: 47144440 Tel: 1122346594 Email: facundocordobadempf@impatrq.com
- Enzo Nazareno Enrique
DNI: 46702979 Tel: 1141460550 Email: enzonazarenoenrique@impatrq.com
- Juan Martin Estevez
DNI: 47144334 Tel: 1162170941 Email: juanmartinestevez@impatrq.com
- Gaston Emanuel Lelio
DNI: 46739611 Tel: 1138563418 Email: gastonemanuellelio@impatrq.com
- Facundo Seoane
DNI: 00000000 Tel: 1125137505 Email: facundoseoane@impatrq.com
- Giuliano Lorenzo Spellbrinck
DNI: 00000000 Tel: 1123670994 Email: giulianolorenzospellbrinck@impatrq.com
- Lucas Valentino Torrekens
DNI: 47119810 Tel: 1127327569 Email: lucasvalentinotorrekens@impatrq.com

# Docentes a tutores:

- Sergio Medina
- Fabricio Carlassara
- Carlos Bianco
- Mauro Minucci
- Julian Scicolone

# Fecha deinicio:

- 1 de Abril de 2024

# Fecha deentrega:

- xx de xx de 2024

# Duración:

- 25 semanas

# Trabajo semanal:

- 8 horas semanales

# Enlaces:

- Instagram: https://www.instagram.com/proyecto_ecosorter24
- LinkTree: https://linktr.ee/Ecosorter

# Objetivo delproyecto:

El objetivo de este proyecto es la colaboración con el reciclaje de basura como medio de contramedida contra la contaminación. Para ello se elaboró un recipiente de basura dónde se clasifica mediante distintos sensores el tipo de material reciclable o residuo. Lo que logra es optimizar tiempos a la hora del proceso de reciclaje ya que aumenta la efectividad de separación de materiales reciclables. El proceso consiste en que al momento de depositar los objetos entrarán en un canasto el cual se moverá hacia el cesto correspondiente. Habrán 4 cestos, plásticos y cartones, vidrio, metales y residuos. Estos cestos tendrán un tamaño variable dependiendo de cuanta capacidad tenga y necesite. La calcificación se llevará a cabo mediante distintos sensores como inductivos, capacitivos y cámaras.

# Semana del 1/4/2024

Esta semana iniciaremos el desarrollo del proyecto, pero antes definiremos nuestro plan mediante un anteproyecto. Su objetivo es proporcionarnos una visión clara de lo que estamos por comenzar. Además, realizaremos una investigación exhaustiva para entender a fondo el funcionamiento y los posibles desafíos que puedan surgir.

# Semana del 8/4/2024

Al haber comenzado tarde, en esta semana pusimos todo nuestro esfuerzo en ponernos al día con las tareas. Empezamos a diseñar la interfaz gráfica para la pantalla en el programa de diseño figma, como también empezamos a confeccionar los planos de la estructura.


# Semana 15/4/2024

En esta semana se comenzó con la programación de los movimientos del canasto generados por un motor paso a paso. En un principio lo íbamos a generar con un motor DC pero por temas de costos nos convenía utilizar un motor paso a paso. También definimos que el carril donde se movería el canasto sería mediante una cadena de bicicleta y un piñón.


También generamos una cuenta en instagram y publicamos el funcionamiento de nuestro proyecto en resumen.


# Semana del 22/04/2024

Esta semana comenzamos con el desarrollo de la estructura. Para esto reciclamos unos cajones de madera, los cuales estaban inutilizados en el taller de aviónica. Desarmamos cada pared y piso de estos con el fin de poder reutilizarlos.


También comenzamos a indagar sobre cómo usar la inteligencia artificial para la detección de imágenes. Aprendimos a como crear un database para su óptimo aprendizaje, por lo que decidimos poner como otro objetivo conseguir imágenes de objetos reciclables.

# Semana 29/04/2024

Las maderas al estar en mal estado debieron ser lijadas por lo que las que era posible lijarlas se lijaron y las que estaban húmedas se dejaron al sol para que se pudieran secar. También se comenzó con el entrenamiento de la inteligencia artificial mediante google colab, ya que cuenta con el hardware necesario para su entreno.


# Semana del 6/05/24

En esta semana se continúo con el entrenamiento de la inteligencia artificial para que le sea posible reconocer botellas fallando varias veces.
También comenzamos con el desarrollo de la página web mediante una aplicación llamada webflow .
Comenzamos a desarrollar el programa para poder medir el porcentaje de cada recipiente del clasificador

# Semana del 13/05/2024

En esta semana pudimos finalizar el entrenamiento de la inteligencia artificial yolo v8 pudiendo detectar botellas exitosamente en fotos. También elaboramos un programa mediante el cual se puede detectar una botella en tiempo real.


Como así también los encargados de las compras conformaron la lista de compras para la cooperadora y así poder obtener los materiales necesarios para la realización del proyecto.

# Semana del 20/05/2024

Esta semana elaboramos el programa para el ajuste de los cubículos si su almacenamiento fuera disparejo. También finalizamos con la maqueta de la interfaz gráfica por lo que pudimos comenzar a programar.


# Semana del 27/05/2024

En esta semana comenzamos a desarrollar el servidor flask el cual hará de backend de la interfaz digital. Desarrollamos la interfaz gráfica mediante html, css y JS pudiendo llegar a algo similar planteado en la maqueta.


# Semana del 03/06/2024

Para el posible ensamblaje de la caja diseñamos el clasificador en autoCAD 3D, por lo que tuvimos que aprender a como utlizarlo. El que nos guió en este proceso fue el profesor scicolone.


Nos dimos cuenta que el canasto en un costado sería poco eficiente por lo que decidimos rediseñarlo y usar tres pistones mas y otra cadena de bicicleta.

# Semana del 10/06/2024

Comenzamos a ensamblar la estructura. Como el diseño de las paredes de las anteriores cajas no encajaban con nuestros plano decidimos desarmarlas para poder elaborarlas de manera tal que coincidieran con las medidas de los planos



# Semana del 17/06/2024

En esta semana pudimos finalizar con el ensamblado de la estructura por lo que nos pusimos en campaña para poder conseguir componentes por lo tanto elaboramos un mensaje con un resumen del proyecto acompañado de lo que necesitábamos.


# Semana del 24/06/2024

En esta semana al haber terminado con una parte de la estructura y no poder comprobar si los códigos funcionaban correctamente debido a la falta de los componentes, se decidió arrancar con la programación de la aplicación para poder usar un sistema de puntos como incentivo del correcto depósito de los materiales a reciclar. Esta aplicación se desarrolló en react native por lo que es compatible para Android y iOS. Durante esta semana aprendimos a como poder usarla para una correcta realización.

# Semana del 01/07/2024

En esta semana llegaron una parte los componentes por lo que pudimos instalarle el sistema operativo de la placa raspberry pi 4 pero no pudimos contar con tiempo para poder probar los ultrasonidos, el sensor inductivo o los fines de carrera. Tampoco pudimos conectar la pantalla LCD debido a que no contábamos con un adaptador micro-hdmi a hdmi.
También pudimos conseguir sponsor por parte de bicicletas Tozzi, los cuales nos proporcionaron piñones y cadenas.

# Semana del 08/07/2024


En esta semana no pudimos trabajar debido a que no pudimos contar con tiempo

# Semana del 29/07/2024

En esta semana volvimos del receso y comenzamos a trabajar con la página web para poder aumentar la difusión del proyecto. También configuramos los sensores de ultrasonido con la raspberry pi 4 pudiendo ya concretar el programa del porcentaje de los cestos (pudimos conectar solo uno porque no contábamos con los cables suficientes).
Por otro lado, avanzamos en la estructura rediseñando el sistema del canasto. Adaptamos un nuevo diseño con el objetivo de hacerlo más estable. El canasto estará fijado a la cadena, la cual se moverá al estar conectada por cuatro piñones a dos ejes sincronizados entre sí. Uno de estos ejes será accionado mediante una correa por un motor. Este motor responderá a la misma lógica que hemos diseñado anteriormente. Después de haber diseñado este sistema empezamos a preparar los ejes colocando los piñones en los mismos. También decidimos emprolijar la tapa del recipiente principal para luego ser pintado.


# Semana del 05/08/2024

En esta semana con respecto a la programación hicimos funcionar los fines de carrera, la pantalla LCD y el sensor que no nos servía ya que se trataba de un sensor de efecto hall. También entrenamos a la inteligencia artificial para que también pudiera detectar envoltorios.
En cuanto a la estructura, hicimos unos soportes L para poder fijar los ejes a la estructura. También confeccionamos los cubículos. Estos todavía no estaban terminados ya que el tipo de madera del que estaban hechos se podrían hinchar por la humedad por lo que debían ser pintados.


# Semana del 12/08/2024

En esta semana nos enfocamos plenamente en la estructura por lo que: pulimos los soportes L, los pintamos y fijamos a estos y los ejes a la estructura. Con esto hecho decidimos que el canasto lo compraríamos en un bazar ya que hacerlo por impresora 3D no era viable. Encontramos un motor de alterna que era factible utilizarlo como motor. También decidimos confeccionar unas guías así el canasto sería más estable.


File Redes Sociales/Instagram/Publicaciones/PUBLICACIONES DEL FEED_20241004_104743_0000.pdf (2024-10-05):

Realizado por: Facundo Seoane 7mo 2da Av ComB


## PUBLICACIONES DEL FEED

PUBLICACION 18/04


PUBLICACION 22/4


PUBLICACION 6/06



PUBLICACION 5/09



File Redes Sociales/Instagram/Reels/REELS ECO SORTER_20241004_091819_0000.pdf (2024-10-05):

Realizado por: Facundo Seoane 7mo 2da Av ComB

## Link:

https://www.instagram.com/reel/C-sIW3zxsh0/?igsh=MXRlbTViYTJyd3Bl

## Link:


https://www.instagram.com/reel/C_tL2XjPzRv/?igsh=MWUyaXpvcDkyNWtlbA==

# REELS DEINSTAGRAM

# REEL DEL15/08

# REEL DEL09/09

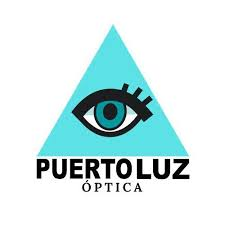
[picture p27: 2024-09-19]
Página web/images/imagen_2024-09-09_144135045.png

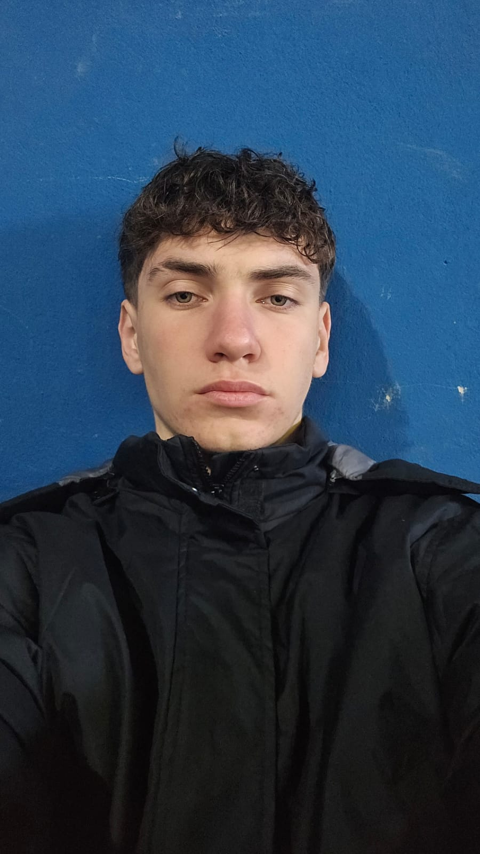
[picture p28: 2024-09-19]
Página web/images/imagen_2024-08-28_082841518.png

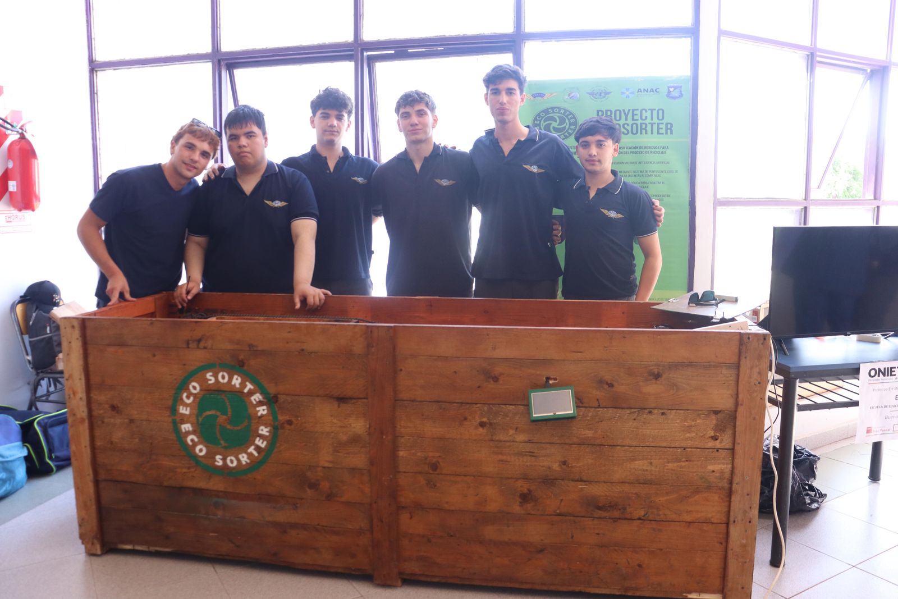
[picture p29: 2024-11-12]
Página web/images/img_9907-min-p-1600.jpg

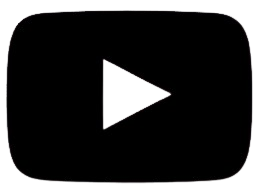
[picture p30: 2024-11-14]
Página web/images/imagen_2024-11-14_114418637-removebg-preview.png

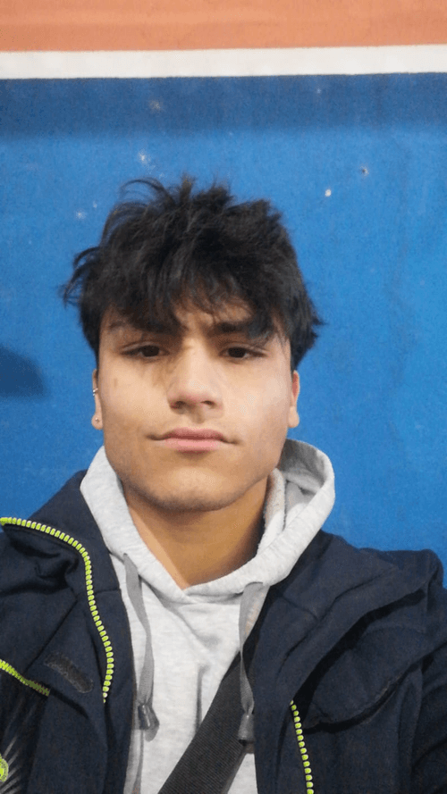
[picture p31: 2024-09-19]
Página web/images/imagen_2024-08-28_082753328-p-500.png

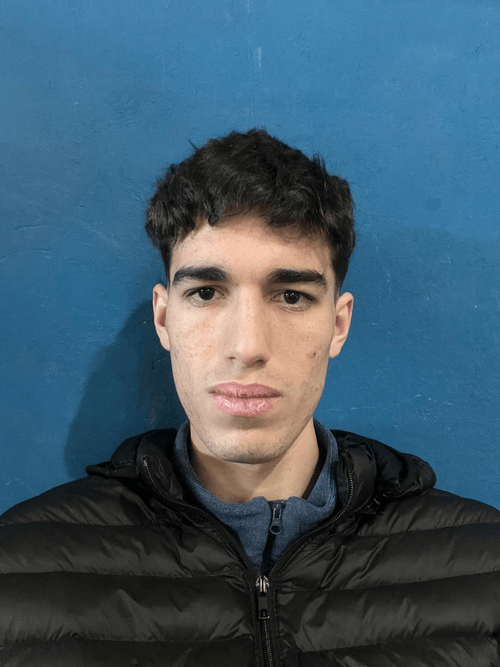
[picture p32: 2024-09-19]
Página web/images/imagen_2024-08-27_110250502-p-500.png

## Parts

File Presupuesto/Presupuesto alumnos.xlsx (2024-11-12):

Fecha | Tipo de Material | cantidad | costo total
2024-07-30 | clavos | 1kg | 7000
2024-08-14 | tornillos | 40 | 6000
2024-08-20 | bulones | 12 | 500
2024-08-20 | cable TPA | 3m | 6000
2024-08-20 | toma macho | 3 | 1200

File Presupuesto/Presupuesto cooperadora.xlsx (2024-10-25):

Fecha | Tipo de Material | cantidad | costo total
2024-08-07 | raspberry pi 4 | 1 | 125000
2024-08-07 | ultrasonido | 4 | 11000
2024-08-07 | fin de carrera | 4 | 6000
2024-09-12 | display | 1 | 20000

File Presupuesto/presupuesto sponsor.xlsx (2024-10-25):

Fecha | Tipo de Material | Cantidad | Costo total | Sponsor
2024-07-06 | cadena | 2 | 12000 | bicicleterias tozzi
2024-07-06 | piñones | 4 | 31000 | bicicleterias tozzi
2024-08-13 | sensor capacitivo | 1 | 50000 | RR Motors
2024-10-12 | motor paso a paso | 1 | 70000 | RR Motors
2024-10-12 | motor paso a paso | 1 | 70000 | padre de Seoane
2024-10-12 | controlador | 3 | 60000 | RR Motors

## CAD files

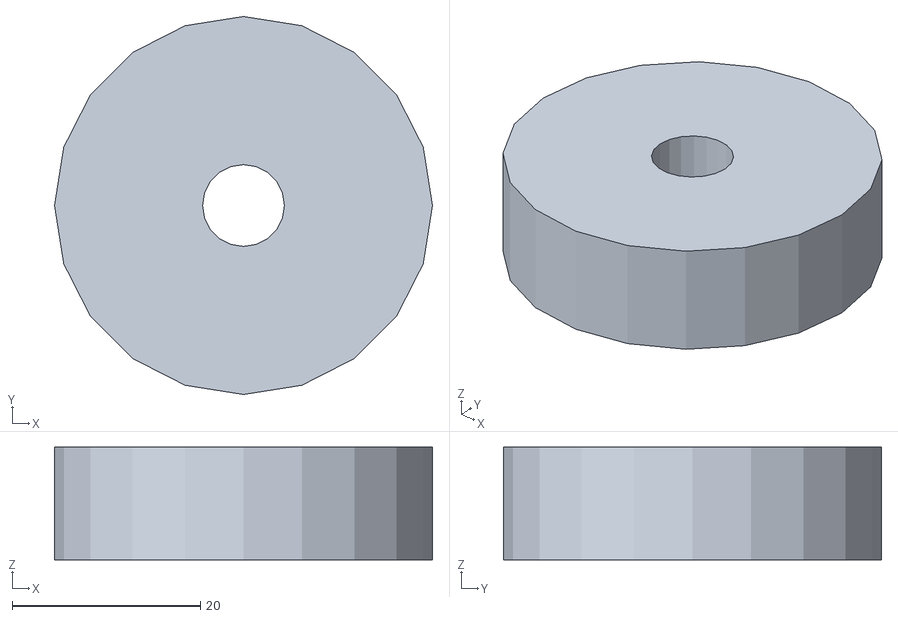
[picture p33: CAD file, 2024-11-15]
impresiones 3D/adaptar motor a canasto.stl
40.2 x 40.2 x 12.0

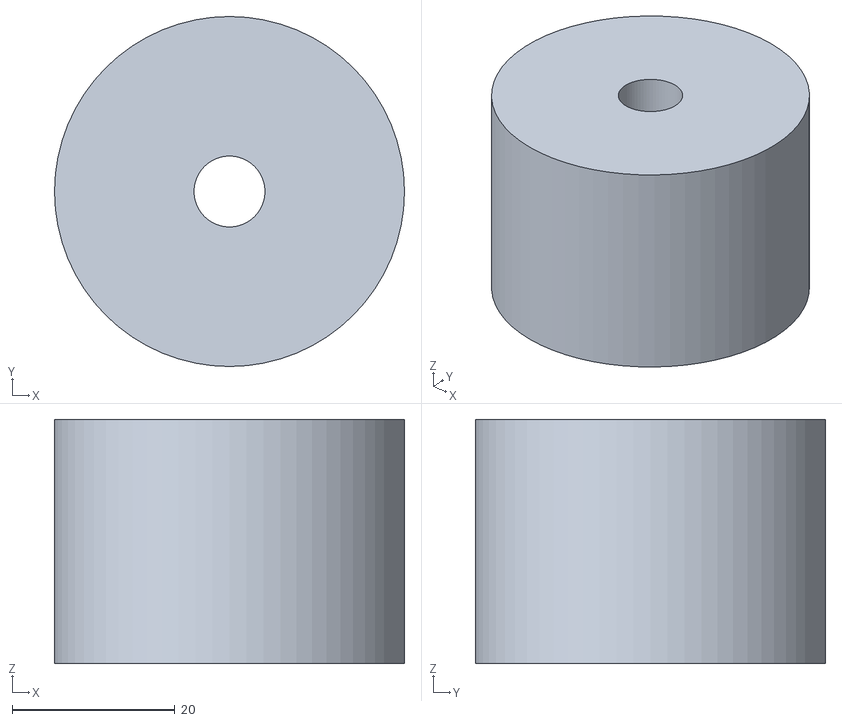
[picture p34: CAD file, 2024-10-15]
impresiones 3D/adaptacion del motor al caño.stl
43.0 x 43.0 x 30.0

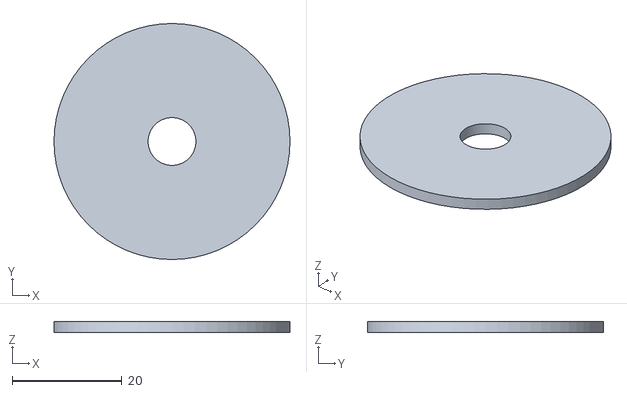
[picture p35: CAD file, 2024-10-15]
impresiones 3D/prueba de adaptacion del motor al caño.stl
43.0 x 43.0 x 2.00

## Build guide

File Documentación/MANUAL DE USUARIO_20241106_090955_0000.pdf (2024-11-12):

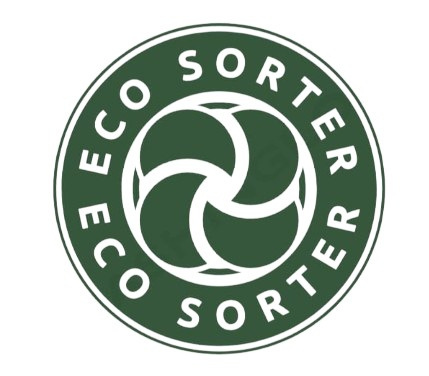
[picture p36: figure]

# DE USUARIO ECO SORTER

# MANUAL

Nombre del proyecto | Eco Sorter
Fecha de Inicio | 1/04/2024
Realizado por | Estevez Juan Martin , Cordoba Dempf Facundo , Seoane Facundo, Lelio Gaston , SpellBrinck Giuliano , Enrique Enzo y Torrekens Lucas

INDICE
Introducción al Funcionamiento Instrucción para depositar Residuos Mantenimiento de almacenamiento Posibles Errores
Como funciona el sistema de Puntos

Eco Sorter es un prototipo de un clasificador de residuos inteligente . El cual consta de un Contenedor (en un principio de madera) qué almacena en su interior 4 cubículos (plástico/metal , vidrios transparentes , carton/papeles y residuos orgánicos ).
Centímetros por arriba de los cubículos se encuentra un canasto (también de madera) el cual posee una cámara Kolke Kec-455 y un sensor capactivo . Cuyo objetivo es facilitarle al programa una clasificación eficiente y rápida del residuo.
Una vez reconocido el tipo de residuo , el canasto se mueve mediante un sistema de Cadenas y Piñones impulsado por dos motores paso a paso hacia el cubículo que corresponde (Figura 1) . Posteriormente el fondo del canasto se abre gracias a un electroiman que deja caer el residuo y vuelve a cerrar la tapa.(Figura 2)
Una vez clasificado el residuo , en la pantalla se observará el sistema de Puntos por reciclaje ( El puntaje asignado dependerá del tipo de residuo que reciclemos).

Figura 1:

1- INTRODUCCION AL
FUNCIONAMIENTO

Figura 2:

Vista general del proyecto:

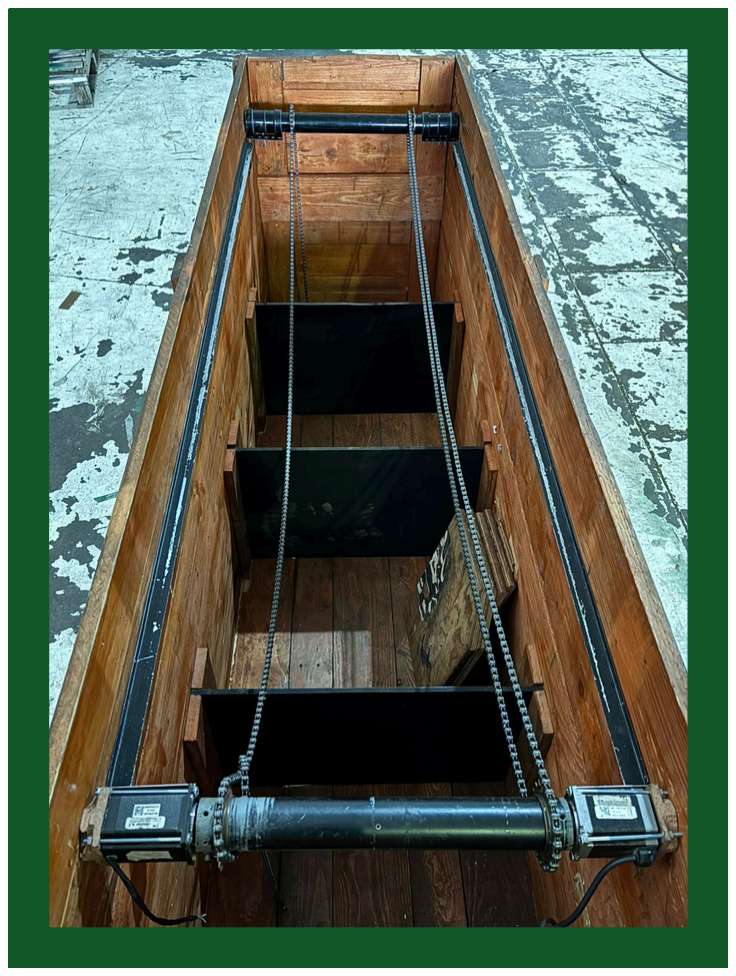
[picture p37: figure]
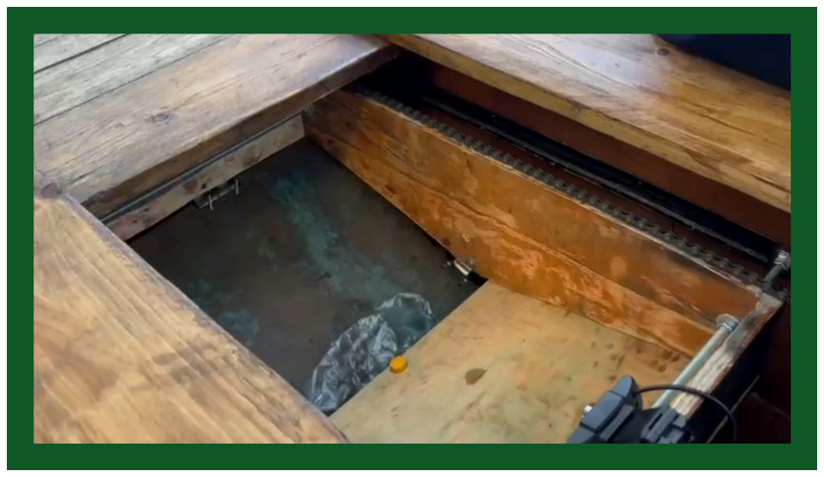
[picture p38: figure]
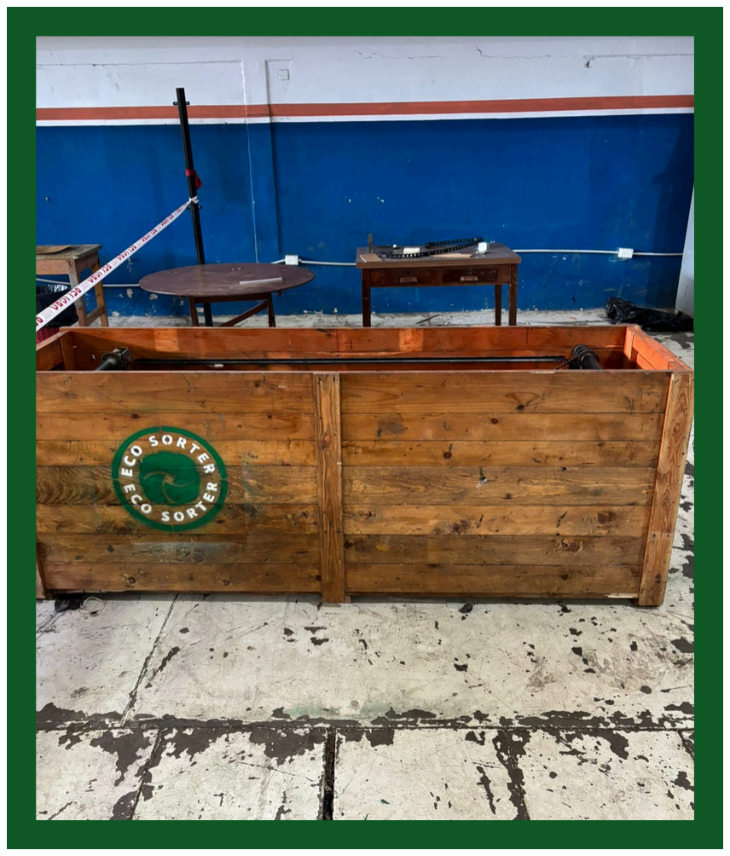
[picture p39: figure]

2- ¿COMO DEPOSITAR RESIDUOS?

Pasos | Advertencias | Estado
Depositar el residuo en el hueco de la parte superior de Eco Sorter | DEPOSITAR UN SOLO RESIDUO A LA VEZ | Listo para recibir un residuo
Esperar a que el sistema realice la clasificación | NO INTRODUCIR OTRO RESIDUO DURANTE ESTE PROCESO | Realizando reconocimiento y clasificación
Escanear QR para sumar puntos | - | Preparándose para un nuevo proceso
Introducir siguiente residuo | DEPOSITAR UN SOLO RESIDUO A LA VEZ | Listo para recibir un residuo

3- MANTENIMIENTO DE
ALMACENAMIENTO

Cuando uno de los cubículos llegue a su máxima capacidad , el sensor ultrasonido avisará al programa del estado del cubículo y se podrá observar en la pantalla una alerta de capacidad máxima alcanzada. Una vez recibida la alerta el usuario debe realizar los siguientes pasos :
•Retirar la bolsa qué se encuentre llena
•Limpiar el cubículo previo a colocar una nueva Bolsa •Colocar una nueva bolsa
•Verificar que el sensor ultrasonido no se haya desconectado al colocarla nueva bolsa
4- POSIBLES ERRORES
Tipo de Error | Solución
Atascamiento | Desconectar la máquina, levantar la tapa y observar que esta produciendo el atascamiento
Mal reciclaje | Asegurarse de que las botellas no tengan líquido antes de colocarlas en Eco Sorter

Alimentación

Revisar que el sistema esté alimentado correctamente

Como parte del incentivo para fomentar el reciclaje, se ha implementado un sistema de puntos en el que cada usuario acumula puntos por depositar correctamente los residuos. Estos puntos acumulados pueden ser canjeados por diversas recompensas disponibles en la sección de catálogos.
La cantidad de puntos obtenidos varía según el material reciclado :

5- SISTEMA DE PUNTOS

Material | Puntos
Vidrio | 10
Metal | 10
Plástico/Cartón | 5
Residuos Orgánicos | 10

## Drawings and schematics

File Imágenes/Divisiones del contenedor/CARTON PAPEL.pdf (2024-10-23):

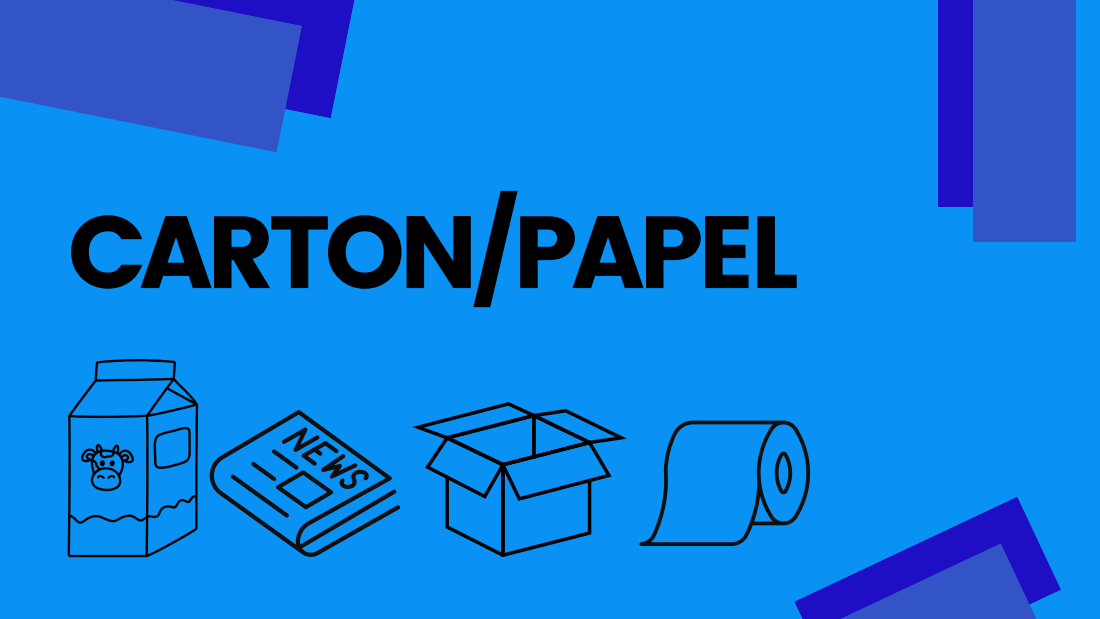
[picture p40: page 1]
CARTON/PAPEL

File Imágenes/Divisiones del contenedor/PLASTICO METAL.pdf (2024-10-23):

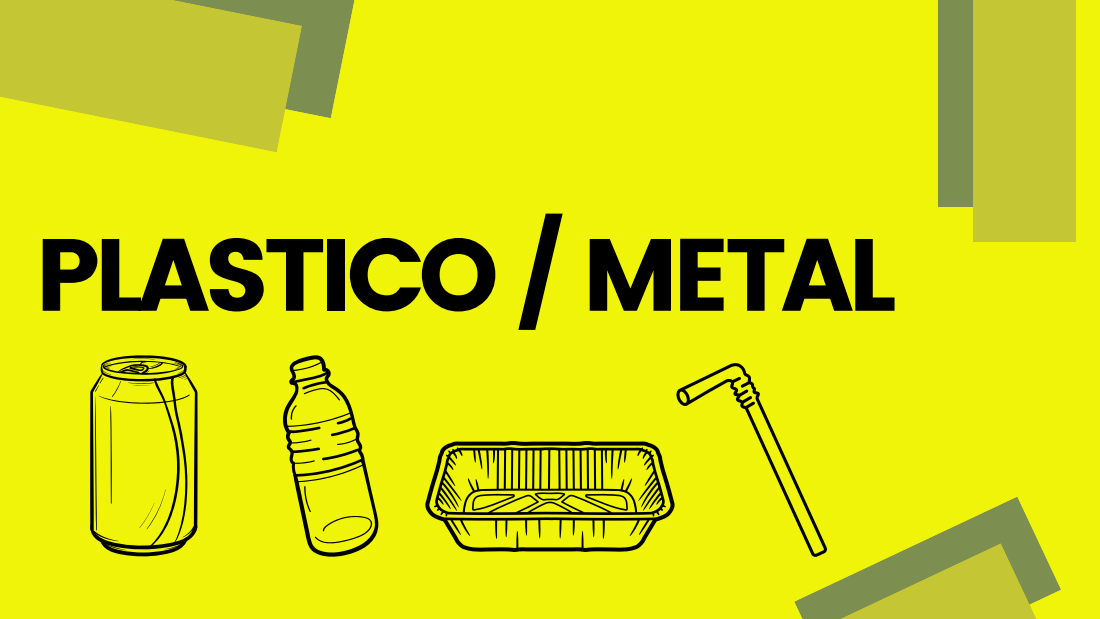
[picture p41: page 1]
PLASTICO / METAL

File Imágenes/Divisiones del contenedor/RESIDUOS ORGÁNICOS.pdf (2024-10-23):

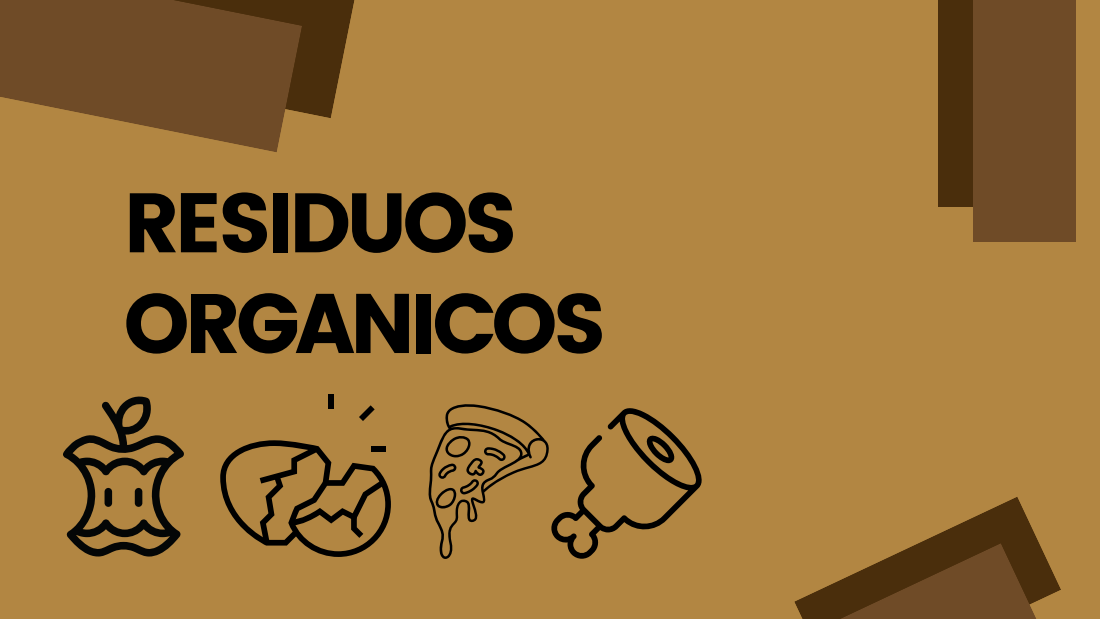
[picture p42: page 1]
RESIDUOS ORGANICOS

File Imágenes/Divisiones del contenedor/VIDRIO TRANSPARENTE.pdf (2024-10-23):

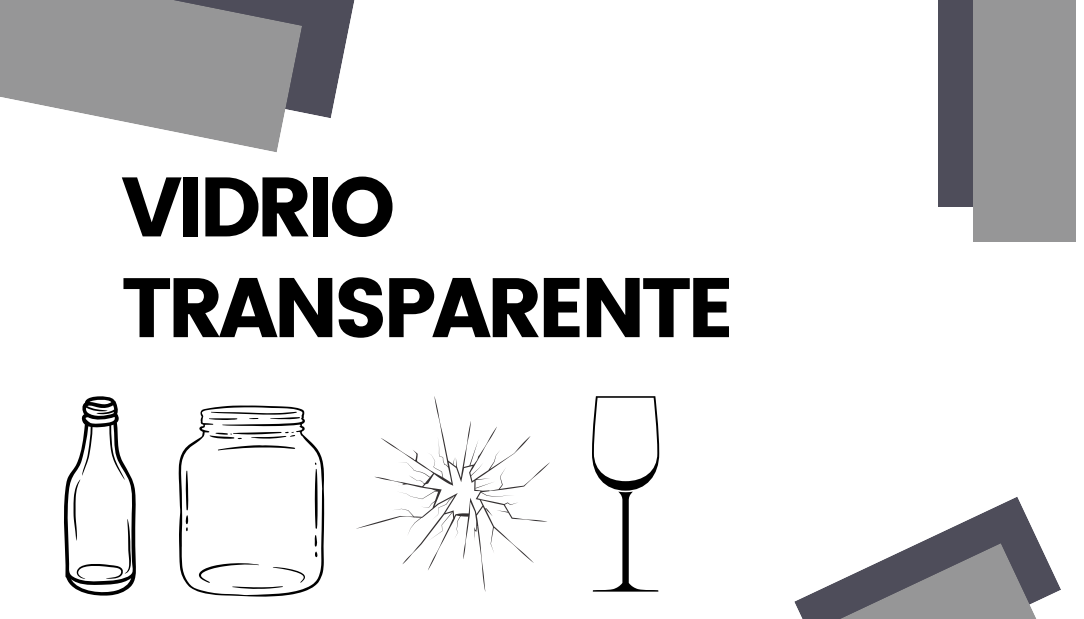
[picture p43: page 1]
VIDRIO TRANSPARENTE

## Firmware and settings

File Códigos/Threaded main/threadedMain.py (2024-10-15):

from ultralytics import YOLO
from enum import Enum
from gpiozero import DistanceSensor
import RPi.GPIO as GPIO
from flask import Flask, render_template, url_for
import threading
from time import sleep

#configurando GPIO
GPIO.setmode(GPIO.BCM)

#Variable para flask
app = Flask(__name__)

#Sensores Ultrasónicos
medidorVid = DistanceSensor(echo= 24, trigger= 23)
medidorPlas = DistanceSensor(echo= 25, trigger= 8)
medidorMet = DistanceSensor(echo= 7, trigger= 12)
medidorRes = DistanceSensor(echo= 16, trigger= 20)

#capacitivo
capacitivo = 20
GPIO.setup(capacitivo, GPIO.IN)

# Declaro las variables para poder mostrar que objeto detectó
varPlas = 0
varMet = 0
varVid = 0
varRes = 0

# Configuración de los pines GPIO del motor para el movimiento de los ejes 
PUL_PIN_1 = 17  # Pin para el pulso 
DIR_PIN_1 = 27  # Pin para la dirección 
GPIO.setup(PUL_PIN_1, GPIO.OUT)
GPIO.setup(DIR_PIN_1, GPIO.OUT)

# Configuración de los pines GPIO del motor para la apertura de la compuerta del canasto
PUL_PIN_2 =  2
DIR_PIN_2 = 3
GPIO.setup(PUL_PIN_2, GPIO.OUT)
GPIO.setup(DIR_PIN_2, GPIO.OUT)

class ModelType(Enum):
    YOLOv8n = 'yolov8n.pt'
    YOLOv8s = 'yolov8s.pt'
    pers = 'ecosorter.pt'

class Camera(Enum):
    LAPTOP = '0'

def mover_motor_eje(pasos, direccion, velocidad):
    # Establecer la dirección
    GPIO.output(DIR_PIN_1, direccion)
    
    for paso in range(pasos):
        # Enviar un pulso al driver
        GPIO.output(PUL_PIN_1, GPIO.HIGH)
        sleep(velocidad)  # Controla la velocidad del motor
        GPIO.output(PUL_PIN_1, GPIO.LOW)        
        sleep(velocidad)

def mover_motor_canasto(pasos, direccion, velocidad):
    # Establecer la dirección
    GPIO.output(DIR_PIN_2, direccion)
    
    for paso in range(pasos):
        # Enviar un pulso al driver
        GPIO.output(PUL_PIN_2, GPIO.HIGH)
        sleep(velocidad)  # Controla la velocidad del motor
        GPIO.output(PUL_PIN_2, GPIO.LOW)        
        sleep(velocidad)

#funcion de medicion
class medir:
    def vid(self):
            try:
                disvid = medidorVid.distance * 100
                sleep(0.1)
            except:
                print("error")
            print (disvid)
            disvid = (disvid / 40) * 100
            capacidadvid = 100 - disvid
            self.capacidadvid = capacidadvid
            return self.capacidadvid

    def plas(self):
        try:
            displas = medidorPlas.distance * 100
            sleep(.01)
        except:
            print("error")
        displas = (displas * 100) / 40
        capacidadplas = 100 - displas
        self.capacidadplas = capacidadplas
        return self.capacidadplas 

    def res(self):
        try:
            disres = medidorRes.distance * 100 
            sleep(.01)
        except:
            print("error")
        disres = (disres * 100) / 40
        capacidadres = 100 - disres
        self.capacidadres = capacidadres 
        return self.capacidadres 

    def met(self):
        try:
            dismet = medidorMet.distance * 100 
            sleep(.01)
        except:
            print("error")
        dismet = (dismet * 100) / 40
        capacidadmet = 100 - dismet 
        self.capacidadmet = capacidadmet
        return self.capacidadmet
                  
#Función detectar objetos
def liveObjectDetection(modelType:ModelType):
    funcionamiento = 0
    
    global varMet
    global varPlas
    global varRes
    global varVid

    model = YOLO(modelType.value)
    
    # Usar 'stream=True' para manejar largos streams
    results = model.predict(source=Camera.LAPTOP.value, stream=True, show=True)
    

    for result in results:
        # Acceder a los nombres de las clases detectadas en los resultados
        for box in result.boxes:
            # Obtener el ID de la clase detectada
            class_id = int(box.cls[0])  
            class_name = model.names[class_id] 

            if GPIO.input(capacitivo) == 0:
                if class_name == 'botella' and funcionamiento == 0:  
                    #Bloqueo la tarea
                    funcionamiento = 1
                    print("Se ha detectado una botella!")
                    # Muevo el canasto al cesto de plástico
                    mover_motor_eje(2000, GPIO.HIGH, 0.001)  

                    # Pausa antes de cambiar de dirección
                    sleep(1)
                    
                    #Abro canasto 
                    mover_motor_canasto(120, GPIO.HIGH, 0.001)

                    sleep(1)

                    #Cierro canasto
                    mover_motor_canasto(120, GPIO.LOW, 0.001)

                    # Mover el motor en la otra dirección
                    mover_motor_eje(2000, GPIO.LOW, 0.001) 

                    #Indico al servidor que objeto detecté
                    varPlas = 1
                    #Libero la tarea 
                    funcionamiento = 0

                elif class_name == 'envoltorio' and funcionamiento == 0:  
                    #Bloqueo tarea
                    funcionamiento = 1
                    print("Se ha detectado un metal!")
                    # Muevo el canasto al cesto de metales
                    mover_motor_eje(2000, GPIO.LOW, 0.001)  

                    # Pausa antes de cambiar de dirección
                    sleep(1)
                    
                    #Abro canasto 
                    mover_motor_canasto(120, GPIO.HIGH, 0.001)

                    sleep(1)

                    #Cierro canasto
                    mover_motor_canasto(120, GPIO.LOW, 0.001)

                    # Mover el motor en la otra dirección
                    mover_motor_eje(2000, GPIO.HIGH, 0.001) 

                    #Indico al servidor que objeto detecté
                    varMet = 1
                    #Libero tarea
                    funcionamiento = 0

                else:
                    print(f"Se ha detectado un objeto: {class_name}")

#Defino funcion para interfaz gráfica 
def servidor():
        
    @app.route("/")
    def index():
            return render_template("index.html")

    @app.route("/medidas")
    def medidas():
            global varVid
            global varMet
            global varPlas
            global varRes

            while True:
                    refrescar = 5
                    vid = int(class_.vid())
                    plas = int(class_.plas())
                    res = int(class_.res())
                    met = int(class_.met())
                    detPlas = 0
                    detMet = 0
                    detRes = 0
                    detVid = 0
                    if varPlas == 1:
                         detPlas = 1
                         refrescar = 15
                         varPlas = 0
                    elif varMet == 1:
                         detMet = 1
                         refrescar = 15
                         varMet = 0
                    elif varRes == 1:
                         detRes = 1
                         refrescar = 15
                         varRes = 0
                    elif varVid == 1:
                         detVid == 1
                         refrescar = 15
                         varVid = 0
                    return render_template("medidas.html",
                                            vid = vid,
                                            plas = plas,
                                            res = res,
                                            met = met,
                                            detPlas = detPlas,
                                            detMet = detMet,
                                            detRes = detRes,
                                            detVid = detVid,
                                            refrescar = refrescar)

                         

if __name__ == '__main__':
    class_ = medir()
    #Creo los hilos
    hiloDeteccion = threading.Thread(target= liveObjectDetection(ModelType.YOLOv8n))
    hiloInterfaz = threading.Thread(target= servidor)

    #Los inicio
    hiloDeteccion.start()
    hiloInterfaz.start()

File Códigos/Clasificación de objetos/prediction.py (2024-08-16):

from ultralytics import YOLO
from enum import Enum

class ModelType(Enum):
    YOLOv8n = 'yolov8n.pt'
    YOLOv8s = 'yolov8s.pt'
    pers = 'ecosorter.pt'

class Camera(Enum):
    LAPTOP = '0'

def liveObjectDetection(modelType: ModelType):
    model = YOLO(modelType.value)
    
    # Usar 'stream=True' para manejar largos streams o videos
    results = model.predict(source=Camera.LAPTOP.value, stream=True, show=True)
    
    for result in results:
        # Acceder a los nombres de las clases detectadas en los resultados
        for box in result.boxes:
            class_id = int(box.cls[0])  # Obtener el ID de la clase detectada
            class_name = model.names[class_id]  # Convertir ID a nombre de la clase
            
            if class_name == 'botella':  # Ajusta al nombre de la clase que te interese
                print("Se ha detectado una botella!")
            elif class_name == 'envoltorio':  # Otro ejemplo de condición
                print("Se ha detectado un envoltorio!")
            else:
                print(f"Se ha detectado un objeto: {class_name}")

if __name__ == '__main__':
    liveObjectDetection(ModelType.pers)

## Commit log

2024-08-16 Feat: agregando el programa flask
2024-08-16 Feat: agregando imágenes de la interfaz
2024-08-16 Feat: agregando la primera escena de la interfaz gráfica
2024-08-16 Feat: agregando la escena donde se muestra las medidas
2024-08-16 Feat: agregando programa de reconocimiento de imágenes
2024-08-16 Feat: agregando la IA
2024-08-16 Feat: agregando imágen del logo para el readme
2024-08-16 Feat: modificando el readme
2024-08-16 Feat: arreglando la carpeta
2024-08-16 Feat: Agregando carpeta de campo
2024-09-09 feat: código de pagina
2024-09-19 feat: subiendo index sistema de puntos
2024-09-19 feat: subiendo el estilo de las páginas
2024-09-19 feat: subiendo conexión a la base de datos
2024-09-19 feat: subiendo programas de registro de usuario
2024-09-19 feat: subiendo programas para iniciar sesión
2024-09-19 feat: subiendo programa para cerrar cesión
2024-09-19 feat: subiendo programa para visualizar los puntos
2024-09-19 feat: subiendo programa para sumar puntos
2024-09-19 feat: subiendo catalogo para recompensas
2024-09-26 delete pagina web
    para actualizar la carpeta de la pagina web tengo q borrar la anterior
2024-10-03 Document:Manual de Usuario
2024-10-03 Document: Manual de Usuario corregido
2024-10-04 Document: Reels de Instagram con avances
2024-10-04 Document: Publicaciones del Feed de Ig
2024-10-04 Document: Reels de Instagram
2024-10-04 feat: agregando suma de 10 puntos
2024-10-04 update suma de puntos
    actualizado para que sume 5 puntos
2024-10-05 feat: añadir sistema de puntos
2024-10-05 cambio de título
2024-10-11 feat: subiendo piezas 3D de poleas para el accionamiento de los ejes móviles
    [poleas reductora.stl]
2024-10-11 feat: actualización de modelo de impresión 3D
    [poleas reductora.stl, poleas reductoras.stl]
2024-10-13 Update Carpeta de Campo
2024-10-14 Feat: Subiendo threaded main
2024-10-15 feat: cilindros huecos q van dentro de los ejes para hacer de adaptación del motor para poder transmitir el movimiento
    [adaptacion del motor al caño (prueba).stl, adaptacion del motor al caño.stl, poleas reductoras.stl]
2024-10-16 Update Carpeta de campo.pdf
2024-10-23 feat: cambio de medidas
    [prueba de adaptacion del motor al caño.stl]
2024-10-23 Document: Divisiones para el Contenedor
2024-10-25 Add imagen primer placa de relés
2024-10-25 document: presupuesto
    [Presupuesto cooperadora.xlsx]
2024-10-25 update: presupuesto coperadora
    [Presupuesto cooperadora.xlsx]
2024-10-25 Delete Imagenes/Imágenes sobre el avance del proyecto/IMG_2751.jpeg
    Por cuestión de organización y estética, se eliminarán las fotos y se crearán carpetas para ordenar por etapas el proceso
2024-10-25 Update imágenes motor README.md
2024-10-25 Update eje y motores README.md
2024-10-25 update: presupuesto sponsor
    [presupuesto sponsor.xlsx]
2024-10-25 Style achicar imágenes de logos README.md
2024-10-25 Update imágenes de los cestos
2024-10-25 Delete Imagenes/VIDRIO TRANSPARENTE.pdf
    Con fines estéticos se mueven los archivos que contienen las imágenes a una carpeta con nombre "Divisiones del contenedor"
2024-10-25 Delete Imagenes/ecosorter.png
    Con fin estético se releva la imagen a la carpeta interna "Imágenes sobre el avance del proyecto"
2024-10-25 Delete Imagenes/logo fondo gris.png
    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
2024-11-06 Document: subiendo Manual de Usuario
    Manual de Usuario con las modificaciones post viaje a Córdoba
2024-11-11 commit:update carpeta de campo eco sorter
2024-11-12 commit: corrección de la carpeta de campo
2024-11-12 Create README.md
    Perfil de LinkedIn
2024-11-12 Create README.md
    Perfil de tiktok
2024-11-12 Update README.md
    Tiktok sobre que es Eco Sorter
2024-11-12 Update README.md
    Tiktok sobre la tecnología utilizada
2024-11-12 Update README.md
    Tiktok sobre los Objetivos de Eco Sorter
2024-11-12 Update README.md
    Tiktok sobre el Impacto Social de Eco Sorter
2024-11-12 Update README.md
    Tiktok concluyendo la explicación
2024-11-14 update: pagina web
    se añadio el link a las redes sociales, en este caso al canal de youtube
2024-11-15 commit:impresion 3D
    impresion del adaptador del motor al canasto
    [adaptar motor a canasto.stl]
2024-12-04 commit: manual de instrucciones de armado eco sorter
    manual de armado del proyecto
